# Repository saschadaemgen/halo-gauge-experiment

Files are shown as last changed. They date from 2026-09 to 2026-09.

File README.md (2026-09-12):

<p align="center">
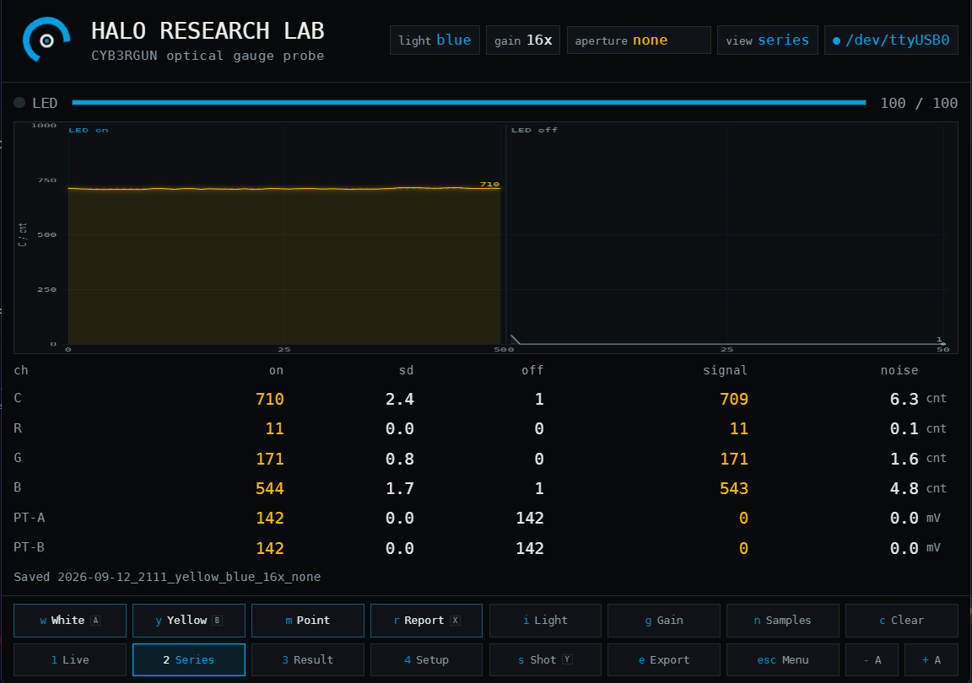
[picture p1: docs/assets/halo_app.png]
HALO LAB
  
</p>

<h1 align="center">halo-gauge-experiment</h1>

<p align="center">
  <strong>Reading an analog pressure gauge optically, from the outside, without touching it.</strong><br>
  A ring of cent-priced sensors, blue light, and the shadow of a needle.
  Open research, including the measurements that failed.
</p>

<p align="center">
  
  
  
  
  
  
</p>

---

The pressure gauge on a pre-charged pneumatic airgun sits inside a sealed,
type-approved system. Screwing in an electronic transducer means opening that
system, which for a gauge under German F-mark approval is not an option for the
owner and elsewhere is at best unwise.

So the needle is read from outside, through the glass, with the original gauge
left exactly as it is. Once the value is digital it can be displayed anywhere,
logged over time, compared against shot data, or fed into a head-up display.

This repository holds the whole thing: the printable test fixture, the probe
firmware, the measurement software, the raw data, and the five versions of the
fixture that were thrown away before the sixth worked.

---

## The Idea

Yellow absorbs blue. Under blue light a yellow needle is dark and a white dial
is bright, and the difference is large enough for a phototransistor that costs
thirty cents.

| | conventional approach | this approach |
|:--|:--|:--|
| **Sensor** | camera plus image processing | 16 to 37 phototransistors in an arc |
| **Contrast from** | ambient light and luck | illumination chosen against the needle pigment |
| **Power** | milliwatts, continuously | microwatts, emitter pulsed per reading |
| **Build height** | needs working distance for optics | under 10 mm over the glass |
| **Smallest dial** | 38 mm commercially | 20 mm |
| **Resolution** | pixels | ratio between two neighbouring sensors |

No image, no inference, no working distance. The pattern of light and dark
across the arc says where the needle is, and the ratio between two adjacent
sensors gives the position between them.

---

## Where This Stands

| Stage | Question | State |
|:--|:--|:--|
| **0** | Is the colour contrast large enough at all | **passed** |
| **0b** | Does the thirty-cent phototransistor see it too | **passed** |
| **0c** | Is blue the reason, or merely brightness | white emitter on order |
| **1** | How does one sensor see the needle sweep past | cards printed, fixture ready |
| **2** | Can two sensors interpolate the position between them | next |
| **3** | Does it survive the glass of a real gauge | after stage 2 |

### Stage 0 Result

Blue emitter, a white card against a card in the needle colour, ambient removed
by sampling with the emitter on and off. The threshold was fixed at an SNR of
10 **before** the first measurement.

| Sensor | White | Yellow | Ratio | Contrast | SNR |
|:--|--:|--:|--:|--:|--:|
| TCS34725, clear | 1068 cnt | 224 cnt | 4.8 | 79 % | 22 |
| TCS34725, blue | 828 cnt | 168 cnt | 4.9 | 80 % | 22 |
| ALS-PT19 | 2286 mV | 451 mV | 5.1 | 86 % | 160 |

Two independent sensors agree on a factor of five. With the emitter dark both
read exactly zero, which is also the proof that the chamber is light tight.

Raw output of every run, including the ones that went wrong, is in
[`docs/log/data/`](docs/log/data).

---

## Why It Matters Beyond One Gauge

Every PCP airgun has the same problem: a small dial, a coloured needle, a
housing nobody may open. What differs between a Huben, an Evanix, a Daystate or
an FX is dial diameter, sweep angle and needle colour.

All three are parameters, not redesigns, and the software treats them as
parameters from the first line. Enter a gauge, set a range and a step, and the
measurement plan, the file names and the printable test cards follow.

**The same method applies wherever a sealed instrument has to stay sealed.**
Diving cylinders, compressors, workshop manometers, breathing apparatus. The
one published patent closest to this project is for the pressure gauge of an
air respirator, for exactly that reason.

---

## The Fixture

A reflectance test bench in black PLA, for under 60 euro in parts.

| | |
|:--|:--|
| **Geometry** | 20/0. Emitter at twenty degrees, sensor looking straight down. Colour measurement normally uses 45/0, but under ten millimetres of build height there is no room for forty-five, and the ring will have the same constraint. |
| **Chamber** | closed box standing on the card. Emitter dark reads 0.00 counts. |
| **Field stop** | exchangeable card with a pierced hole. Printed holes below 1.5 mm do not exist after printing, which is why the aperture left the printer. |
| **Sensor pocket** | takes either sensor, so nothing but the sensor changes between two runs. |

This is **not** a spectrophotometer. Such an instrument measures absolutely and
calibrated, costs five figures, and measures under its own illumination. This
one measures relatively, white against yellow, under exactly the light source
and geometry the product will use. For this question that is the more relevant
number. For a colour standard it would be nonsense.

Parts, orientation and print settings: [`hardware/jig/README.md`](hardware/jig/README.md)
Method, wiring and evaluation: [`docs/method/measurement.md`](docs/method/measurement.md)
Six versions and why five were scrapped: [`docs/log/jig-versions.md`](docs/log/jig-versions.md)

---

## The Probe

A Heltec WiFi LoRa 32 V2 carrying a TCS34725 colour sensor and two ALS-PT19
phototransistors. It samples N times with the emitter on and N with it off,
returns mean and standard deviation per channel, and computes nothing else:
every number in this repository comes from the raw data, not from the firmware.

It speaks the same protocol over USB and over TCP, so the cable to the bench
computer can be pulled off, and it updates itself over WiFi, so the fixture can
be screwed shut for good.

```
w   white card        i   switch emitter, blue or white
y   yellow card       g   cycle colour sensor gain
m   one needle position, labelled by the software
n   samples per half series, 10 / 25 / 50 / 100
r   report contrast and SNR
```

---

## HALO LAB

<p align="center">
  HALO LAB measurement screen
</p>

The measurement front end. It reads the probe, shows the running series full
screen, and files every result three ways: a readable text record, the raw
JSON, and a row in an SQLite database. Gauges, campaigns and needle positions
are managed in the app, and the measurement plan is computed from the range and
the step size.

It runs as a self-contained instrument on a Clockwork uConsole, which boots
straight into it with no desktop in sight, and equally on any PC.

```bash
python3 software/labui/halo_lab.py --port /dev/ttyUSB0
# then open http://127.0.0.1:8760
```

Details: [`software/labui/README.md`](software/labui/README.md) and
[`software/launcher/README.md`](software/launcher/README.md)

---

## Getting Started

### 1. Print the fixture

Eleven parts, black PLA, 0.20 mm, no supports. See
[`hardware/jig/README.md`](hardware/jig/README.md) for orientation, which is
the part that is easy to get wrong.

### 2. Print the cards

```bash
python3 tools/make_cards.py --scale 3 --from 16 --to 24 --step 0.5 --show-radius
```

At 100 %, no scaling. Every sheet carries a ruler so a wrongly scaled print is
obvious before it is measured.

### 3. Wire and flash

Wiring table in [`docs/method/measurement.md`](docs/method/measurement.md).
Open [`firmware/halo_gauge_probe/`](firmware/halo_gauge_probe) in the Arduino
IDE, board **Heltec WiFi LoRa 32(V2)**, upload.

### 4. Measure

```bash
pip3 install pyserial
python3 software/labui/halo_lab.py --port COM6
```

White card, yellow card, report. Twenty seconds each.

---

## Contributing

**The most useful contribution is a measurement on a gauge this project has not
seen.** Another needle colour, another dial size, another manufacturer. If the
method holds across gauges, everything after it is calibration.

Negative results are wanted as much as positive ones. A gauge where this does
not work is worth more than a third one where it does.

Two house rules: measurements over opinions, and failures stay in the log.
[`CONTRIBUTING.md`](CONTRIBUTING.md)

---

## Prior Art

This is not the first optical gauge reader and does not pretend to be.

| | |
|:--|:--|
| **BAM, 2006** | reflective light barriers in a ring around a pointer axis, WO 2007/147609 |
| **Cypress Envirosystems, 2008** | clip-on camera reader, 38 to 114 mm dials, plus or minus 1.5 % of full scale |
| **Siemens, 2019** | patented sensor ring with triangular elements, active until 2040 |
| **AI-on-the-edge-device, 2020** | ESP32-CAM with TensorFlow Lite, the open source camera route |

What is new here: the wavelength chosen against the needle pigment, a 20 mm
dial, and published measurements. The delineation from the Siemens claim is
deliberate and documented, down to the design rule that follows from it.

Sources and the full review: [`docs/research/prior-art.md`](docs/research/prior-art.md)

---

## Repository

```
docs/research/      prior art: patents, commercial devices, open source
docs/method/        how the measurement is done and evaluated
docs/log/           build log, discarded versions, raw data
hardware/jig/       printable fixture, bill of materials, print settings
hardware/cards/     printable test cards
tools/              card generator for any dial, range, sweep and scale
firmware/           probe firmware for a Heltec WiFi LoRa 32 V2
software/labui/     HALO LAB, the measurement front end
software/launcher/  the terminal it runs on
```

---

## Licence

| What | Where | Licence |
|:--|:--|:--|
| Firmware, software, tools | `firmware/`, `software/`, `tools/` | **GPL-3.0-only** |
| Hardware, printable parts, card artwork | `hardware/` | **CERN-OHL-S-2.0** |
| Documentation and measurement data | `docs/`, `README.md` | **CC-BY-SA-4.0** |

Build it, change it, sell it. Keep the notice, say what you changed, pass the
same freedom on. Full text and the reasoning: [`LICENSE.md`](LICENSE.md)

---

## Origin and Trademarks

This project started inside the CYB3RGUN development and is published as a
standalone community project.

Huben, GK1 and any other manufacturer or product names are trademarks of their
respective owners. This project is not affiliated with or endorsed by any of
them. The test dials in this repository are original artwork and not copies of
any manufacturer's dial: only the geometry follows a real gauge, and geometry
is technical, not protectable.

<p align="center">
  <sub>Sascha Dämgen, 2026. Measured, not assumed.</sub>
</p>

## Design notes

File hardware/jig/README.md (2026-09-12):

# Test fixture V6

A light tight reflectance fixture with a 20/0 geometry, an exchangeable field
stop, and one pocket that takes either sensor. Printed in black PLA, all parts
flat, no supports, every bore vertical in print orientation.

See `docs/log/jig-versions.md` for how it got here and what not to repeat.

## Printed parts

| file | qty | size mm | print orientation |
|---|---|---|---|
| gauge_jig_base.stl | 1 | 120 x 120 x 4 | as exported, pocket up |
| jig_v6_rail.stl | 1 | 120 x 60 x 4 | flat |
| jig_v6_frame.stl | 1 | 46 x 46 x 14 | flipped: the face with the small 24 mm opening on the bed |
| jig_v6_slide.stl | 1 | 46 x 46 x 2 | flat, card recess up |
| jig_v6_carrier.stl | 1 | 46 x 46 x 26 | flat, board pocket up |
| jig_v6_lid_tcs.stl | 1 | 46 x 46 x 2 | flat |
| jig_v6_lid_pt19.stl | 1 | 46 x 46 x 2 | flat |
| jig_v6_led_holder.stl | 2 | 26 x 46 x 22 | as exported, standing on the slanted face |
| jig_v6_led_cap.stl | 2 | 11 x 28 x 3 | flat |
| jig_v6_pt19_insert.stl | 1 | 20.3 x 20.3 x 3.2 | flat, pocket up |
| jig_v5_pinhole_plates.stl | 1 print, four plates | 28 x 28 x 0.4 each | flat |

## Not printed

- M3 x 40, four off, through carrier and slide into the frame
- M3 x 10, four off, two per LED cap
- 2 LEDs, 5 mm, clear lens, one blue around 470 nm and one cold white
- 2 resistors to suit the supply, or an LED lead with one built in
- 2 logic level MOSFETs and 2 resistors of 47 k for the gate pull-down
- black photo card, matte, cut to 28 x 28 mm, hole pierced or drilled in the
  centre. This is the field stop. It does not come out of a printer.
- a TCS34725 breakout on the Adafruit 1334 layout, or an ALS-PT19 on the
  Adafruit 2748 layout. Headers soldered to the top, so the board lies
  component side down.

## Orientation, the part that is easy to get wrong

**Frame:** the open chamber with the two window cutouts goes face down onto the
card. The closed face with the small 24 mm opening and the print texture faces
up. Turn it the other way and the LEDs shine into a wall.

**LED holders:** flat face on the card, slanted face outwards. The LED goes in
from the slanted face, so its light leaves at the vertical inner face and
crosses the window of the frame on its way down to the spot.

**Slide:** recess up, the aperture card drops into it.

**Carrier:** pocket up, the sensor board lies in it component side down.

## Assembly

Card in the pocket, rail on the four pegs, frame in the middle of the rail
window, an LED holder either side of it. Slide on the frame, aperture card in
its recess, carrier on top, four long screws. Sensor board into the pocket, lid
on, done. LEDs in from outside, caps with two short screws each.

## Print settings, Bambu Lab P1S or P2S

Layer height 0.20 mm. The card recess in the slide is 0.4 mm deep, which is
exactly two layers. Another layer height rounds it to the wrong depth.

Black PLA. Lowest shrinkage of the common filaments, which matters for a stack
of parts that has to fit together, and black because white and clear filament
carry light through the walls.

Four perimeters, 30 % gyroid, seam aligned or rear. Check that the seam does
not fall inside the LED bore.

X-Y hole compensation stays at zero. It acts on every hole equally while small
holes shrink more than large ones, so no single value suits 2.5, 5.4 and 8 mm
at once. Ream the M3 tap holes with 2.5 mm and the LED bore with 5.5 mm only if
the LED will not slide in.

Print the slide first. It takes minutes, and if the aperture card sits in its
recess the rest is worth printing.

## Geometry

- card surface: 0
- frame chamber: 0 to 12, opening 24 x 24 from 12 to 14
- slide: 14 to 16, aperture card at about 15.75
- carrier: 16 to 42
- LED axis crosses the frame wall at 8.1 above the card, at 20 degrees

Spot diameter on the card is roughly 1.7 times the aperture plus 0.3 mm.

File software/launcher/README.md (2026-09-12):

# CYB3RGUN research terminal

Turns a Clockwork uConsole into an instrument: it boots into a menu of the
project's applications, no desktop, no Linux in sight.

## What it does

- `launcher.py` serves the start screen on port 8750 and knows which
  applications exist, whether they are running, and how to start them
- `apps.json` is that list. Adding a tool is an entry in a file, not code
- two systemd user services keep the launcher and HALO LAB alive across reboots
- the browser starts full screen on the launcher as soon as it answers
- `boot-splash.sh` replaces the Raspberry boot screens with the project's own

## Install

```
cd ~/halo-gauge-experiment
bash software/launcher/install.sh
bash software/launcher/boot-splash.sh
sudo reboot
```

Both scripts keep a backup of anything they change and can be run again
safely. `install.sh` appends to the labwc autostart rather than replacing it.

## The application list

```json
{
  "key": "1",
  "name": "HALO LAB",
  "line": "optical gauge probe",
  "detail": "contrast, needle sweep, campaigns",
  "url": "http://127.0.0.1:8760",
  "check": "127.0.0.1:8760",
  "service": "halo-lab"
}
```

`url` sends the browser somewhere, `run` starts a program, `check` is a
host:port that decides whether the tile shows as running, and `soon: true`
greys a tile out for something not built yet.

## Keys

Digits 1 to 9 start an application, `r` refreshes, `p` opens power, plus and
minus change the text size. The uConsole game buttons A, B, X and Y start the
first four tiles. The text size is remembered.

## Notes

Chromium is started with `--password-store=basic`, otherwise it asks for a
keyring password on every start, which on a kiosk is asking nobody.

If the power buttons do nothing, `systemctl poweroff` needs a polkit rule or a
sudoers line for this user.

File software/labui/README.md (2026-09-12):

# HALO LAB

Measurement front end for the halo-gauge-experiment probe. It reads the Heltec
board over USB, shows the running measurement full screen, and records every
finished series and report into `docs/log/data/`.

Built for the Clockwork uConsole at 1280 x 720, runs the same on any PC.

## Install

Only pyserial is needed. Everything else is the Python standard library.

    sudo apt install python3-serial          # Raspberry Pi OS
    pip3 install pyserial                    # anywhere else

For the screenshot button, `scrot` must be present. Without it the button
reports what is missing and nothing else breaks.

    sudo apt install scrot

## Run

    python3 software/labui/halo_lab.py --list          # which ports exist
    python3 software/labui/halo_lab.py                 # uses /dev/ttyUSB0 or COM6
    python3 software/labui/halo_lab.py --port COM6
    python3 software/labui/halo_lab.py --simulate      # no hardware, fake data

Then open http://127.0.0.1:8760

To reach it from another machine, for example the board on a PC and the screen
on the uConsole:

    python3 software/labui/halo_lab.py --host 0.0.0.0

Kiosk mode on the uConsole:

    chromium-browser --kiosk --app=http://127.0.0.1:8760

## Using it

The board is switched into JSON mode automatically on connect. Every button in
the footer is also a key on the keyboard, the letter is printed on the button.

| key | does |
|---|---|
| w | measure the white card |
| y | measure the yellow card |
| r | report contrast and SNR |
| i | switch light source, blue or white |
| g | cycle the colour sensor gain |
| c | clear stored results |
| s | screenshot into `docs/log/images/` |

Fill in the aperture field before measuring. It goes into the file names and
into the header of every record, which is the only way to tell two otherwise
identical series apart later.

## What gets written

Per finished series and per report, into `docs/log/data/`:

- `YYYY-MM-DD_HHMM_<target>_<light>_<gain>_<aperture>.txt`, the human readable
  record with a header naming firmware, light, gain, aperture and note
- the same stem with `.json`, holding the raw firmware object plus that metadata

Every serial line, parseable or not, is appended to
`docs/log/data/session_YYYY-MM-DD.log` with a timestamp. If anything else goes
wrong, that file still has the measurement in it.

## Colours

The palette is the experiment, not decoration. Blue is the light source and
anything the operator triggers, yellow is the needle and its measured values,
white is the dial. A go verdict is blue. A failed threshold is grey, because a
low reading is a result and not a fault. The only red is a lost serial link.

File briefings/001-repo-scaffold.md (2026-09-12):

# Briefing 001: Repository scaffold for halo-gauge-experiment

Author: Mausi (master chat)
Executor: Claude Code (CC)
Repository: https://github.com/saschadaemgen/halo-gauge-experiment (private)
Local root: C:\Projects\CYB3RGUN\HUBEN\halo-gauge-experiment

## Goal

Move the files that already sit in the local root into the repository layout, add the documentation files from the scaffold package, configure Git LFS for binary assets, and push four commits.

## Working rules

- Stop at the first failure and report the exact output. Do not improvise.
- Do not edit the content of any .md, .ino, .stl or .png file. This briefing is about placement and Git only.
- No em dashes anywhere in files you create. Use normal hyphens.
- Conventional Commits, one commit per concern, messages given below.

## Step 0: Verify state

```
git remote -v
git status
git lfs version
```

Remote must point to saschadaemgen/halo-gauge-experiment via SSH. Report the branch name. If Git LFS is missing, STOP and report.

List the current root. Expected: five `jig_v5_*.stl`, `jig_v5_sections.png`, `mhg01.png`, `mhgz01.png`, and the unpacked scaffold folder.

## Step 1: Target layout

```
halo-gauge-experiment/
  README.md
  .gitignore
  .gitattributes
  briefings/001-repo-scaffold.md
  docs/
    research/prior-art.md
    method/measurement.md
    log/jig-versions.md
    log/data/.gitkeep
  hardware/
    jig/README.md
    jig/gauge_jig_base.stl
    jig/jig_v5_frame.stl
    jig/jig_v5_slide.stl
    jig/jig_v5_carrier.stl
    jig/jig_v5_led_holder.stl
    jig/jig_v5_rail.stl
    jig/jig_v5_sections.png
    cards/mhg01.png
    cards/mhgz01.png
    cards/README.md
  firmware/probe/halo_gauge_probe.ino
```

Move the existing files with `git mv` where they are already tracked, plain move otherwise. `mhg01.png` is the dial artwork, `mhgz01.png` is the needle artwork.

Create `hardware/cards/README.md` with exactly this content:

```markdown
# Test cards

Source artwork exported from Illustrator, 1:1, dial diameter 20 mm.

- `mhg01.png` dial face without needle
- `mhgz01.png` needle, separate layer

Card format is 100 x 100 mm. The card set (full white, full yellow, nine dial cards with the needle at 0 to 40 MPa in 5 MPa steps) is generated from these two files. Print all cards on the same printer and paper.
```

## Step 2: .gitignore

```
# OS
Thumbs.db
.DS_Store

# Editors
.vscode/
.idea/

# Arduino build output
firmware/**/build/
*.bin
*.elf
```

## Step 3: .gitattributes and LFS

```
*.stl filter=lfs diff=lfs merge=lfs -text
*.png filter=lfs diff=lfs merge=lfs -text
*.jpg filter=lfs diff=lfs merge=lfs -text
*.pdf filter=lfs diff=lfs merge=lfs -text
*.3mf filter=lfs diff=lfs merge=lfs -text
```

Run `git lfs install` once. Because the STL and PNG files may already be committed as plain blobs, run `git lfs migrate import --include="*.stl,*.png" --everything` only if `git log --oneline | wc -l` is greater than 0 and the files appear in history. If the repository has no commits yet, skip the migration. Report which case applied.

## Step 4: Commits

```
chore(repo): add gitignore, gitattributes and LFS tracking
docs: add README, prior art, measurement method and jig version log
feat(hardware): add test jig v5 STL files, base plate and card artwork
feat(firmware): add halo gauge probe sketch for Heltec WiFi LoRa 32 V2
```

Then `git push -u origin <branch>`.

## Report back

1. Branch name and remote
2. Whether LFS migration was needed and its result
3. The four commit hashes and the push result
4. `git ls-files` output

No suggestions for next steps. Those come from the master chat.

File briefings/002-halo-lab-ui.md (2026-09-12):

# Briefing 002: HALO LAB, measurement software for the uConsole

Author: Mausi (master chat)
Executor: Claude Code (CC)
Repository: https://github.com/saschadaemgen/halo-gauge-experiment
Development machine: Windows PC, C:\Projects\CYB3RGUN\HUBEN\halo-gauge-experiment
Target machine: Clockwork uConsole, CM4, Clockwork Raspberry Pi OS image, 1280 x 720
Hardware under test: Heltec WiFi LoRa 32 V2 on USB, firmware probe-0.2

## Goal

A local measurement application that reads the probe firmware over USB, shows the running measurement on the uConsole screen, and writes every finished series to disk as a raw log and a JSON record. It replaces the serial monitor for all further experiments, and every screen of it will end up as a photograph in a public forum post.

## Working rules

- Stop at the first failure and report the exact output. Do not improvise around a missing dependency, report it.
- Ask before adding any dependency that is not in the list below.
- Code, comments, docstrings and UI text in English. No em dashes anywhere.
- Do not touch anything under `firmware/`, `hardware/`, `docs/research/` or `docs/method/`.
- Do not invent measurement logic. All numbers come from the firmware. The UI computes nothing except formatting.
- Conventional Commits, commit messages at the end.

## Protocol, firmware probe-0.2

Serial, 115200 baud, 8N1. The firmware starts in human readable mode. Sending `j` switches it to JSON mode and it answers with a `hello` object. In JSON mode every line is exactly one JSON object with a `type` field. Single character commands, no line ending required:

| key | effect |
|---|---|
| `j` | toggle JSON mode, emits `hello` when switching on |
| `p` | emit `hello` again (status poll) |
| `w` | run a series on the white card |
| `y` | run a series on the yellow card |
| `r` | emit the report for every light source that has both targets |
| `i` | switch light source, blue or white, emits `ack` |
| `g` | cycle TCS34725 gain 1x / 4x / 16x / 60x, emits `ack` |
| `l` | toggle live stream, emits `ack` |
| `c` | clear stored results, emits `ack` |

Object types:

```
{"type":"hello","fw":"probe-0.2","tcs":0,"oled":1,"light":"blue","gain":"16x","samples":50}
{"type":"ack","cmd":"g","light":"blue","gain":"60x","live":1}
{"type":"live","t":123456,"c":0,"r":0,"g":0,"b":0,"pta":2286.3,"ptb":142.0,"sat":0,"light":"blue","gain":"60x"}
{"type":"run","target":"white","light":"blue","gain":"60x","samples":50}
{"type":"sample","target":"white","led":1,"n":0,"c":0,"r":0,"g":0,"b":0,"pta":2286.0,"ptb":142.0}
{"type":"series","target":"white","light":"blue","gain":"60x","samples":50,"saturated":0,
 "on":{"C":[1067.70,38.53],"R":[...],"G":[...],"B":[...],"PT-A":[...],"PT-B":[...]},
 "off":{...},"signal":{"C":1067.70,...},"noise":{"C":38.53,...}}
{"type":"report","light":"blue","saturated":0,
 "channels":[{"ch":"C","unit":"cnt","white":1067.70,"yellow":224.10,"contrast":0.7901,"noise":38.76,"snr":21.80,"go":1}, ...],
 "best":"B","best_snr":22.00,"go":1}
{"type":"error","msg":"unknown command x"}
```

In `on`/`off` each channel is `[mean, sd]`. Channel order is always C, R, G, B, PT-A, PT-B. `contrast` is a fraction, display it as a percentage. A run emits one `run`, then 100 `sample` objects (50 with `led:1`, 50 with `led:0`), then one `series`. A run takes about 20 seconds.

Unparseable lines are not an error: the firmware may print a boot banner or a stray human line. Ignore any line that is not valid JSON, but keep it in the raw log.

## Architecture

Python 3 on the uConsole. A local HTTP server on 127.0.0.1:8760 serves one page and a websocket. The browser runs in kiosk mode and shows it full screen. Reason for this split: the same code runs on a normal PC, and the screen is easy to make look good.

Dependencies, all from apt or pip on the Pi: `pyserial`, `websockets`, `aiohttp`. Nothing else. No build step, no npm, no bundler. The page is one HTML file with inline CSS and JavaScript plus the logo SVG, served from `software/labui/static/`.

```
software/labui/
  README.md            how to install and run, on the Pi and on a PC
  halo_lab.py          server: serial reader, JSON parser, websocket, file writer
  static/index.html    the whole UI
  static/cyb3rgun_logo.svg
```

Serial port: default `/dev/ttyUSB0`, override with `--port`. On Windows `COM6`. Add `--list` to print available ports and exit. If the port is missing or busy, the UI must still load and show a clear disconnected state with the port name and a retry button. Reconnect automatically every 2 seconds while disconnected.

## Files written per series

Directory `docs/log/data/`, created if missing. Two files per finished series, same stem:

`YYYY-MM-DD_HHMM_<target>_<light>_<gain>_<aperture>.txt` and `.json`

`<aperture>` comes from an input field in the UI, free text, default `none`, sanitised to lowercase with non alphanumerics replaced by `-`. The `.txt` is a human readable record in the same layout the firmware prints in text mode, with a header block naming date, firmware version, sensor, light, gain, aperture, sample count and the operator note. The `.json` holds the raw `series` object plus that same metadata under a `meta` key.

A report is written as `YYYY-MM-DD_HHMM_report_<light>_<aperture>.txt` and `.json` when it arrives.

Every raw serial line, JSON or not, is appended to `docs/log/data/session_YYYY-MM-DD.log` with a millisecond timestamp. That file is the fallback if anything else goes wrong.

## Screen

Fixed 1280 x 720, no page scrolling, nothing may be cut off. Design it once for that size, do not build a responsive grid.

Layout, left to right:

```
+--------------------------------------------------------------+
| [logo]  HALO LAB          blue - 60x - 1.0 mm     probe-0.2   |  56 px header
+---------------------+----------------------+-----------------+
|  LIVE               |  SERIES              |  RESULT         |
|  six channel bars,  |  the running series   |  report table,  |
|  value in mV / cnt  |  as a strip chart,    |  one row per    |
|  saturation flag    |  LED on and off runs  |  channel, GO or |
|                     |  drawn apart          |  no per row     |
|                     |                      |  verdict block  |
+---------------------+----------------------+-----------------+
|  w white   y yellow   r report   i light   g gain   c clear   |  72 px footer
+--------------------------------------------------------------+
```

Behaviour:

- The header always shows the current light source, gain and aperture, because every photograph of this screen has to be self explanatory.
- During a run the whole screen shows it: a progress bar with the sample count, the LED state as a labelled indicator, and the strip chart filling left to right. The other panels stay visible but dim.
- When a `series` arrives, its numbers replace the series panel: mean and sd for LED on and off, signal and noise per channel, saturation warning if the firmware sets it.
- When a `report` arrives, the result panel fills. The verdict block states the best channel, its SNR and whether the threshold of 10 is met, in words, not just a colour.
- The footer buttons send the keys. They are also bound to the keyboard, because the uConsole has one. Show the key letter on each button.
- An aperture field and a one line operator note field sit in the footer. Both go into the file metadata. Changing them does not send anything to the firmware.
- A camera button saves a PNG screenshot of the page into `docs/log/images/` with the same name stem as the last series. Use `html2canvas` only if it can be vendored as a single local file, otherwise leave the button out and say so in the report.

## Visual direction

The palette is not decoration, it is the experiment: the light source is blue, the needle is yellow, the dial is white. Use exactly those three as the meaningful colours and let the rest be dark and quiet.

```
--bg      #0A0C0E   near black, the inside of the light chamber
--panel   #12161A   panel fill
--line    #1E252B   hairlines and panel borders
--ink     #C9D3DA   body text
--dim     #6B7A85   labels and secondary text
--beam    #009FE3   CYB3RGUN blue, the light source, primary accent
--needle  #FCB803   needle yellow, measured from the gauge artwork
--dial    #F1EFE8   dial white
```

Rules for using them: the blue belongs to the light and to anything the operator triggers. The yellow belongs to the yellow card and its measured values. The white belongs to the white card. A GO verdict is blue, not green. A failed threshold is dim grey, not red, because a low contrast reading is a result and not a fault. The only red in the application is a lost serial connection.

Type: one monospace family for everything, because this is an instrument and the numbers must align. Use the stack `"DejaVu Sans Mono", "Liberation Mono", monospace`, which is present on the Clockwork image. No web fonts, the machine may be offline. Measured values are the largest type on the screen. Labels are small and quiet, in sentence case, not all caps.

The logo sits top left at 28 px, unmodified, in its own blue. Do not tint it, do not put it behind anything, do not repeat it.

Motion: exactly two moving things, the live bars and the strip chart, both driven by data. No transitions on buttons, no fades, no glow. The instrument look comes from precision and alignment, not from effects. Do not add scan lines, grid overlays, flicker, glitch text or terminal typing effects.

Numbers: fixed decimal places per channel, right aligned, with the unit in a separate dim column so the digits line up. Never let a value change its width while updating.

## Acceptance

1. `python3 halo_lab.py --list` prints the available serial ports.
2. With the Heltec connected, `python3 halo_lab.py` starts, the page loads at http://127.0.0.1:8760, the header shows firmware version and light source within two seconds.
3. Unplugging the Heltec shows the disconnected state, plugging it back in recovers without restarting the program.
4. Pressing `w` runs a series, the progress and the strip chart follow it live, and afterwards the numbers match what the firmware printed.
5. After `w`, `y` and `r`, four data files and one session log exist under `docs/log/data/` and the values in them match the screen.
6. The page fits 1280 x 720 with no scrollbar and no clipped text.

## Commits

```
feat(labui): add serial reader and websocket server for probe-0.2
feat(labui): add HALO LAB measurement screen
docs(labui): add install and run instructions
```

## Build hint

No firmware change in this briefing, so no flashing. On the uConsole: `git pull`, then `python3 software/labui/halo_lab.py`. If dependencies are missing, report the exact `pip install` line rather than running it blind.

## Report back

1. Python version on the PC and, if you touched it, on the uConsole
2. The dependency list actually installed
3. Whether the screenshot button was implemented, and if not, why
4. A description of what the screen shows in the disconnected state
5. The three commit hashes and the push result

No suggestions for next steps.

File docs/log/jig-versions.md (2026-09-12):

# Test fixture, version history

How the fixture got to V6, and why each version was thrown away. The reasons
are the design rules for the sensor ring, which is why they are written down.

## V1, 2026-09-08

Base plate with a card pocket, a bridge over it carrying the sensor board, and
five printed aperture discs of 5 mm diameter with holes from 0.6 to 3.0 mm.
LED channels bored at 28 degrees through the solid bridge.

Discarded:

- The 0.6 mm printed hole did not exist after printing, even at 0.08 mm layer
  height. FDM does not make clean holes below about 1.5 mm.
- 5 mm discs are too small to handle and cannot be seated repeatably.
- Angled bores through a solid body print badly. The roof of the bore sags and
  the LED sits crooked.
- The tunnel under the bridge was open along both long sides, so ambient light
  reached the card from the side.

## V2 and V3, 2026-09-09

The same bridge with light skirts along both edges, first with a 0.3 mm gap
above the card, then touching it. Fixed the side leak and none of the rest.

## V4, 2026-09-09

First modular stack: frame, aperture slide, sensor carrier, clamshell plugs for
3 mm LEDs, rail. Every part flat, every bore vertical in print orientation, the
aperture moved out of the printer and into a pierced black card.

Discarded before printing: the LEDs on hand are 5 mm, and the clamshell plug
does not scale to a 5 mm body inside the frame.

Lesson: confirm the dimensions of a component before drawing its holder.

## V5, 2026-09-09

The 5 mm LEDs moved out of the frame into their own blocks standing beside it,
each with a straight bore aimed at the measurement spot and an outer face cut
perpendicular to that bore, so the part prints standing with the bore vertical.
Pins of 1.75 mm filament aligned the stack.

Discarded: the pins align but hold nothing. The stack rattled, and a rattling
stack changes the geometry between two series, which is the one thing a
reference fixture must not do.

## V6, 2026-09-10, current

```
base plate   120 x 120 x 4    card pocket, four pegs
rail         120 x 60 x 4     locates frame and LED holders on the card
frame        46 x 46 x 14     light chamber, windows in two walls
slide        46 x 46 x 2      holds the aperture card
carrier      46 x 46 x 26     sensor pocket, 8 mm shaft
lid          46 x 46 x 2      closes the sensor pocket, slot for the header
LED holder   26 x 46 x 22     two off, 5 mm LED at 20 degrees
LED cap      11 x 28 x 3      two off, presses the LED flange flat
insert       20.3 x 20.3 x 3.2  carries an ALS-PT19 in the sensor pocket
```

Everything is screwed with M3 straight into the printed plastic. The stack no
longer moves between series.

### Rules that came out of V1 to V5

1. Every printed bore is vertical in its print orientation.
2. No printed hole below 1.5 mm. Small apertures go into black card.
3. Anything that has to be handled is at least 20 mm across.
4. Light tightness is a closed box standing on the target, not a roof over it.
5. Alignment is not fixation. If it can rattle, it will, and it will do it
   between two series.
6. Component dimensions are confirmed before the holder is drawn.

### Things that cost an evening and are worth writing down

**The breadboard rail is split in the middle.** The MOSFET had no ground at
all, and every measurement that followed was wrong until a multimeter found it.

**A logic level MOSFET from an unknown batch may not be one.** With 3.3 V on
the gate it held 2.1 V across drain and source instead of under 0.1. The LED
lit, dimly, and the contrast measurement still worked because contrast is a
ratio. The absolute numbers from that session are not comparable with later
ones and are labelled accordingly.

**The tower was a mistake.** A carrier that hangs the sensor deeper into the
chamber sounds like it gets closer to the card. It got further away, and the
phototransistor sat on the converter floor until the short carrier went back in.

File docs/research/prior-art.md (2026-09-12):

# Prior art

Last reviewed: 2026-09-09. This page is a technical review, not legal advice.

## Summary

Reading a pointer instrument optically from the outside is an old idea. Three families exist:

1. Reflective sensor rings: several light sensors on an arc above the dial, the pointer shades some of them. Documented since 2006, refined and patented by Siemens in 2019.
2. Camera based readers: image the dial, find the needle by image processing. Commercial since 2008, open source since 2020.
3. Mechanical or magnetic retrofits: magnet on the Bourdon tube with a Hall sensor, or replacing the gauge with a transducer. Invasive, not applicable to a sealed, type-approved pressure system.

This project belongs to family 1. It does not claim to have invented the sensor ring. What it adds is listed at the end.

## Patents

### Siemens AG, US 12,044,549 B2 and DE 10 2019 207 322 B4

Title: Optical reading device for a pointer instrument. Inventors: Ralf Huck, Stefan Klehr. Priority 2019-05-20 (DE 10 2019 207 322.0). US grant 2024-07-23, active until 2040-10-31. German family member granted 2021-07-29, active.

https://patents.google.com/patent/US12044549B2/en
https://patents.google.com/patent/DE102019207322B4/en

Claim 1 (US):

> An optical reading device of a pointer instrument having a pointer and a scale face or dial with different reflection properties, comprising: an illumination apparatus for illuminating the scale face or dial of the pointer instrument; and a plurality of triangular light sensor elements which are arranged in a circle about a rotation axis of the pointer for capturing light of the illumination apparatus reflected back by the scale face or dial of the pointer instrument; wherein the illumination apparatus is configured to evenly illuminate the scale face or dial at least in a region opposite the circle; and wherein the plurality of triangular light sensor elements each substantially formed as isosceles triangles and are each arranged adjacent to one another along a circumferential direction of the circle.

The inventive core is the triangular element shape. Because adjacent isosceles triangles are offset by half their base width, the pointer always shades two neighbours at once and the ratio of the two shadings gives a continuous position. Dependent claims cover 180 degree alternation, abutting limbs, triangular light guides made of transparent plastic, and ambient light collection.

Relevance to this project: the sensor elements here are rectangular SMD phototransistors (0603) behind printed baffles. They are not triangular and not arranged as abutting isosceles triangles. As read by the authors, claim 1 is therefore not met. Design rule derived from this: no triangular sensor elements, no triangular light guides. A freedom-to-operate opinion by a patent attorney is planned before any commercial sale, with DE 10 2019 207 322 B4 as the primary reference.

Technical lessons taken from the description: switch the LED on only for the duration of a reading; use an ambient light sensor to skip the LED when daylight suffices; uniform illumination of the sensed arc is essential and Siemens uses an annular light guide for it.

### BAM, WO 2007/147609 A2

Bundesanstalt fuer Materialforschung und -pruefung. Monitoring device for a measuring device. Priority June 2006.

https://patents.google.com/patent/WO2007147609A2/en

Describes a light source and a sensor fastened on the glass of a pointer instrument, working as a reflective light barrier that detects when the pointer reaches a predetermined position, and several such units arranged in a ring around the pointer axis to capture the position in segments. Mounting on an acrylic carrier by screws, snap fit or adhesive.

This is the sensor ring in its coarse, segment-wise form and is the closest published ancestor of this project. Any national patents from this application expire in 2027 at the latest. Status to be checked in DEPATISnet before commercial sale.

### Further patents cited by the Siemens examiner

- Rosemount Inc., US 2014/0239151 A1, self-powered optical detector for mechanical gauge instruments (2013).
- Shanghai Fire Research Institute, CN 103234593 A, digitizer for the pointer pressure gauge of an air respirator (2013). Closest application: small gauge on a sealed breathing air system.
- Lipman Science and Technology, US 2008/0048879 A1, automatic monitoring of analog gauges (2004).
- Baumer Bourdon-Haenni, EP 2905595 A1, gauge testing device, camera based (2014).

## Commercial products

### Cypress Envirosystems Wireless Gauge Reader (WGR)

https://cypressenvirosystems.com/products/wireless-gauge-reader-2/

Clip-on reader for existing gauges, on the market since 2008, patented. Reads the needle optically, transmits wirelessly. Gauge diameters 38 to 114 mm, accuracy stated as +/- 1.5 % of full scale. The user manual lists an image capture mode, so the device is camera based.

Lessons: "non-invasive, the pressure system stays sealed" has been the central selling argument of this device class for 17 years. +/- 1.5 % of full scale is the benchmark to beat or match. Dials below 38 mm are not served.

## Open source

### AI-on-the-edge-device

https://github.com/jomjol/AI-on-the-edge-device

ESP32-CAM with TensorFlow Lite, reads water, gas and electricity meters including the small analog pointer dials, everything on the device. Large community, maintained since 2020, commercial boards available.

Why this project does not use a camera: power. The sensor ring needs a few photodiodes and a briefly pulsed LED, which allows battery or energy harvesting operation. A camera plus inference costs orders of magnitude more energy and does not fit a device that lives in a pistol grip.

## What this project adds

1. Spectral contrast optimisation. None of the sources above selects the illumination wavelength for the needle pigment. The Huben GK1 needle is yellow on a white dial. Yellow pigment absorbs blue, so blue illumination (around 470 nm) with a broadband detector maximises the needle to dial contrast. This is the hypothesis the first experiment tests.
2. Dial size. Commercial readers start at 38 mm. This project targets a 20 mm dial with 0603 phototransistors at about 1.3 mm pitch on a 7 mm radius.
3. Application. A type-approved airgun pressure system that must not be modified, read from a battery powered grip.
4. Published method. Test jig, test cards, SNR threshold and raw data are public, including negative results.

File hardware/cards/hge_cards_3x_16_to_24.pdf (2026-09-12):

## HGE-D01 16.0 MPa

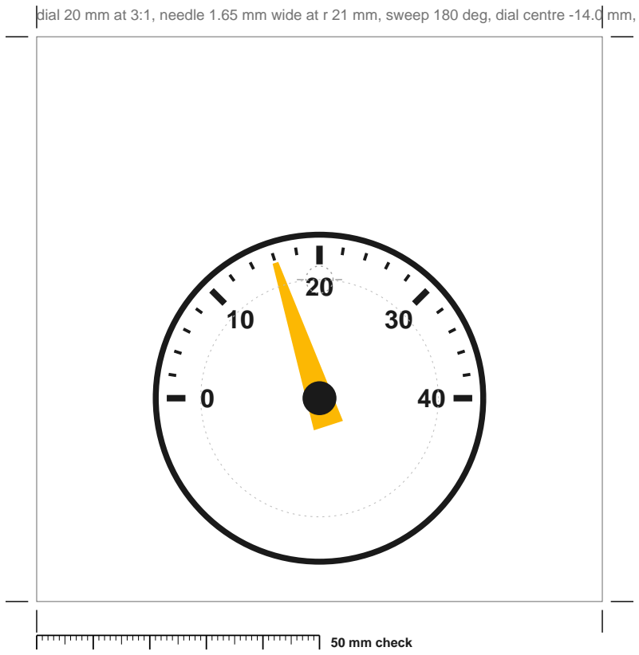
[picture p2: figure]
50 mm check

dial 20 mm at 3:1, needle 1.65 mm wide at r 21 mm, sweep 180 deg, dial centre -14.0 mm, 1 of 17

PRINT AT 100 %, NO SCALING. halo-gauge-experiment, Sascha Daemgen. Original artwork, not a copy of any manufacturer's dial.

## HGE-D02 16.5 MPa

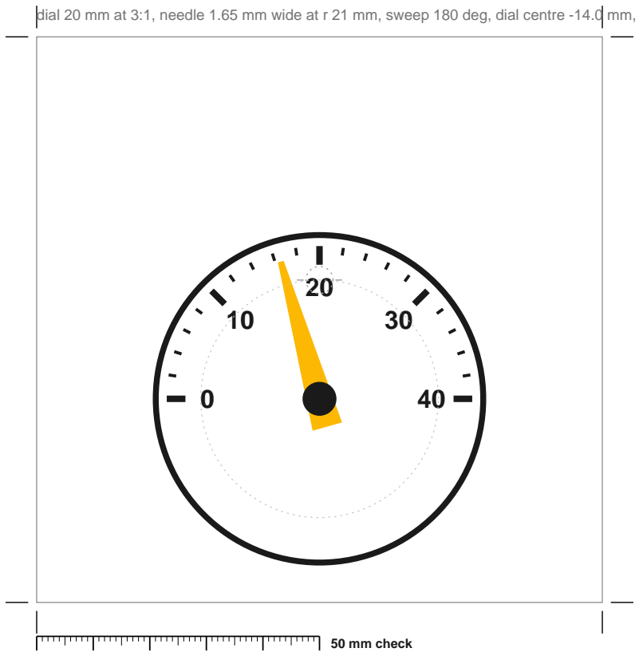
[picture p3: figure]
50 mm check

dial 20 mm at 3:1, needle 1.65 mm wide at r 21 mm, sweep 180 deg, dial centre -14.0 mm, 2 of 17

PRINT AT 100 %, NO SCALING. halo-gauge-experiment, Sascha Daemgen. Original artwork, not a copy of any manufacturer's dial.

## HGE-D03 17.0 MPa

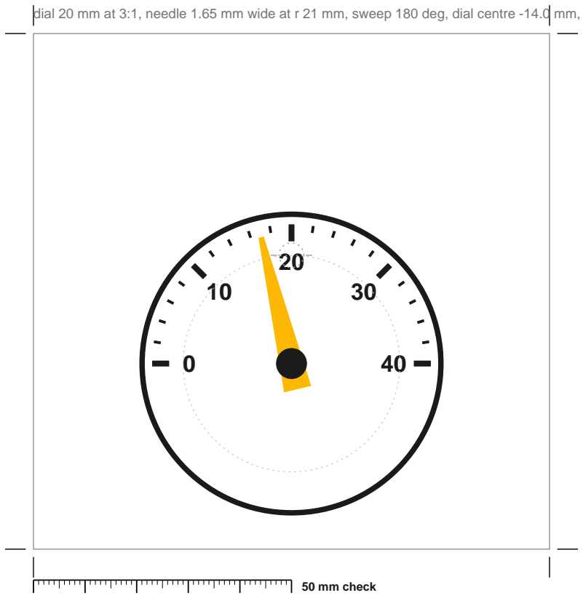
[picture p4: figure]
50 mm check

dial 20 mm at 3:1, needle 1.65 mm wide at r 21 mm, sweep 180 deg, dial centre -14.0 mm, 3 of 17

PRINT AT 100 %, NO SCALING. halo-gauge-experiment, Sascha Daemgen. Original artwork, not a copy of any manufacturer's dial.

## HGE-D04 17.5 MPa

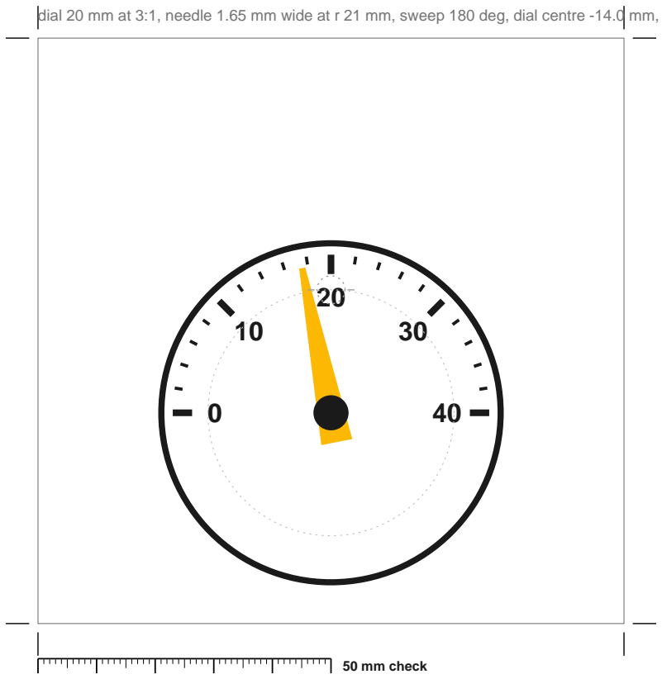
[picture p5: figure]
50 mm check

dial 20 mm at 3:1, needle 1.65 mm wide at r 21 mm, sweep 180 deg, dial centre -14.0 mm, 4 of 17

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

## HGE-D05 18.0 MPa

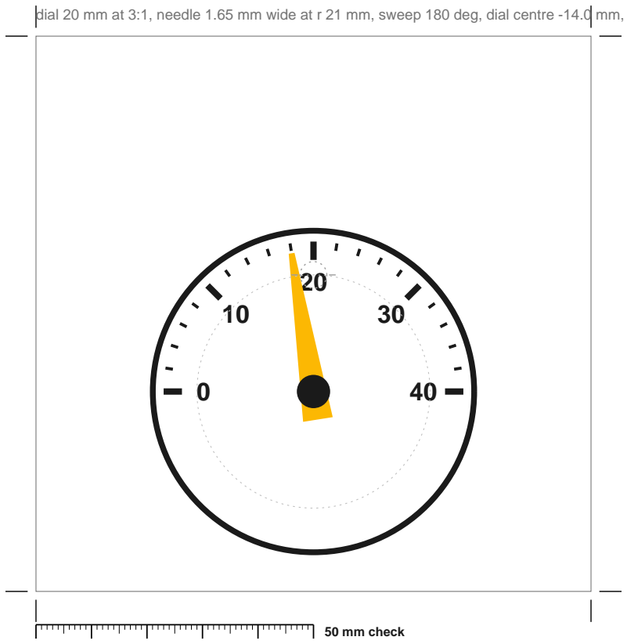
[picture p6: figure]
50 mm check

dial 20 mm at 3:1, needle 1.65 mm wide at r 21 mm, sweep 180 deg, dial centre -14.0 mm, 5 of 17

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

## HGE-D06 18.5 MPa

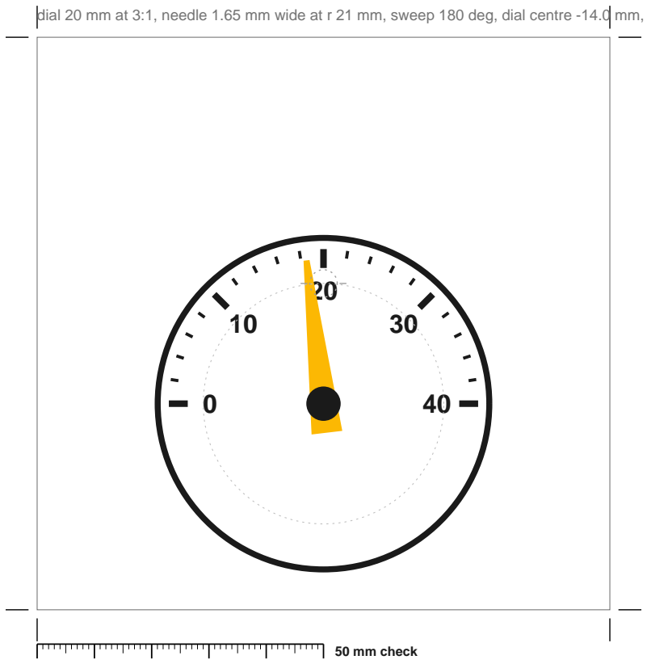
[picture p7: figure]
50 mm check

dial 20 mm at 3:1, needle 1.65 mm wide at r 21 mm, sweep 180 deg, dial centre -14.0 mm, 6 of 17

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

## HGE-D07 19.0 MPa

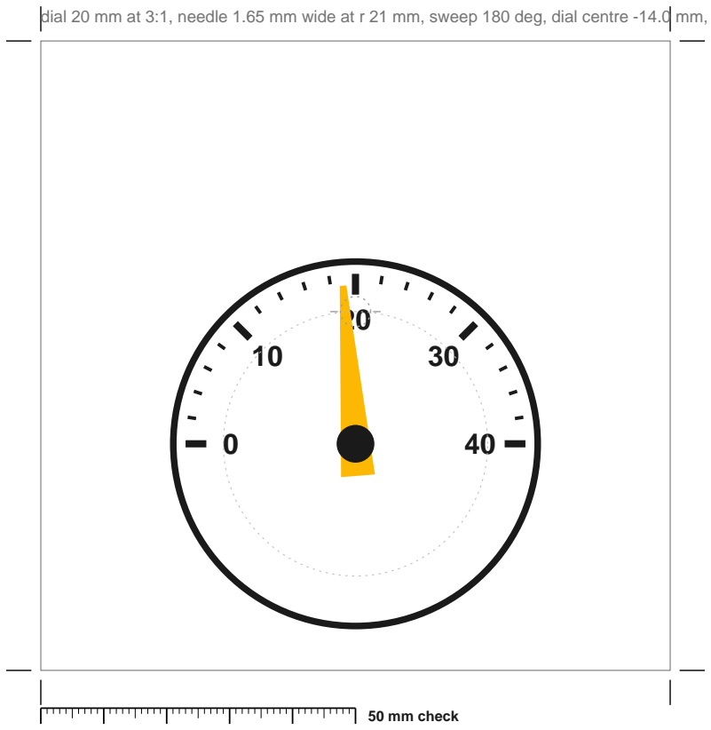
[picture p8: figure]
50 mm check

dial 20 mm at 3:1, needle 1.65 mm wide at r 21 mm, sweep 180 deg, dial centre -14.0 mm, 7 of 17

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

## HGE-D08 19.5 MPa

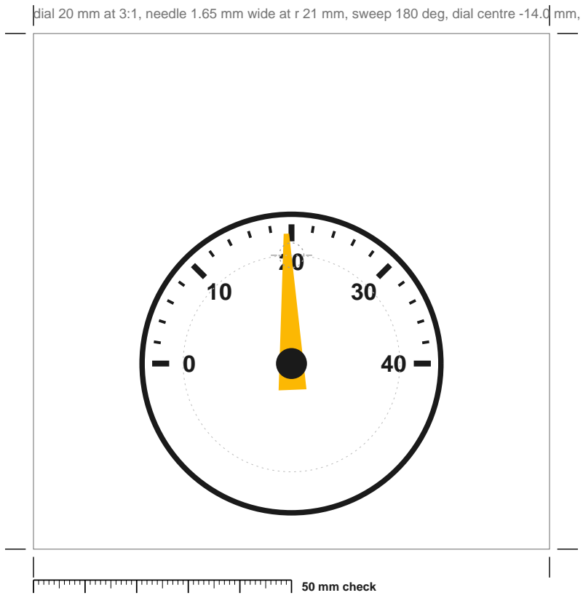
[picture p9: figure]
50 mm check

dial 20 mm at 3:1, needle 1.65 mm wide at r 21 mm, sweep 180 deg, dial centre -14.0 mm, 8 of 17

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

## HGE-D09 20.0 MPa

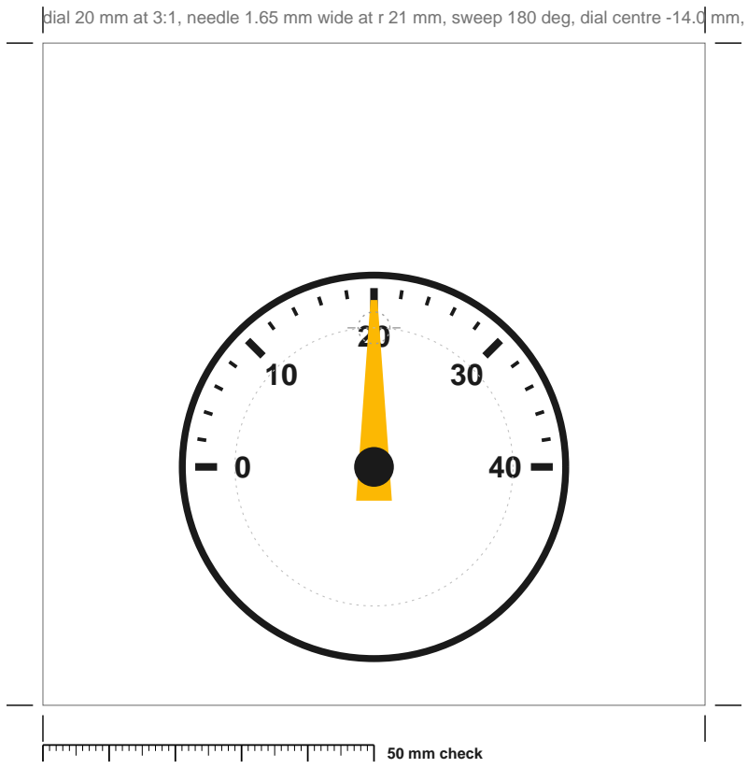
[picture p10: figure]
50 mm check

dial 20 mm at 3:1, needle 1.65 mm wide at r 21 mm, sweep 180 deg, dial centre -14.0 mm, 9 of 17

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

## HGE-D10 20.5 MPa

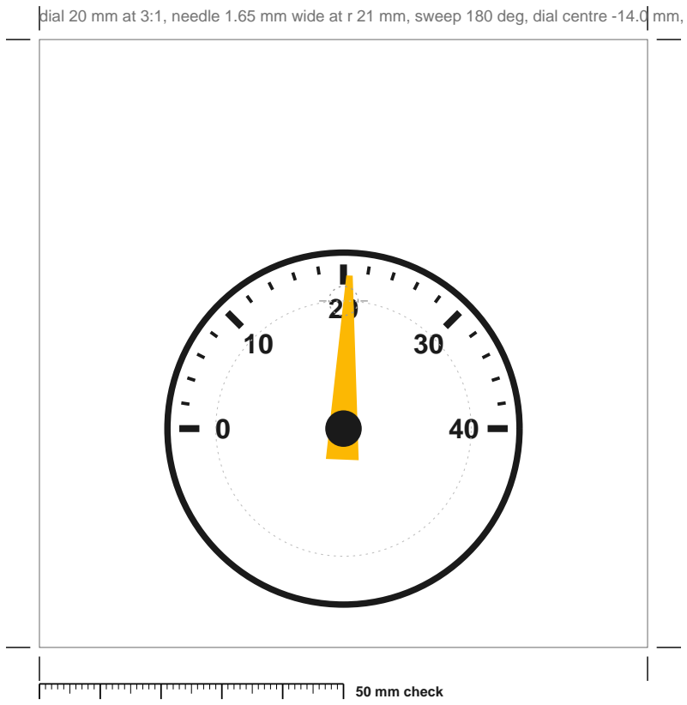
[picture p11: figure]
50 mm check

dial 20 mm at 3:1, needle 1.65 mm wide at r 21 mm, sweep 180 deg, dial centre -14.0 mm, 10 of 17

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

## HGE-D11 21.0 MPa

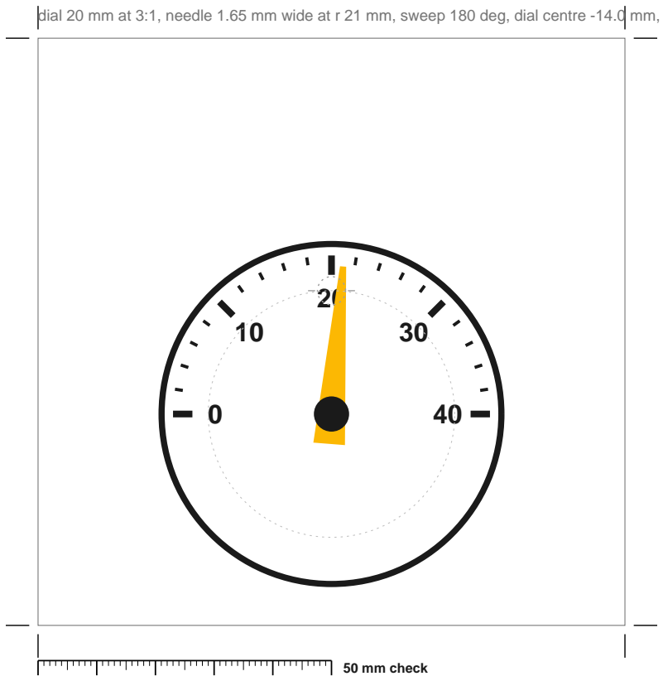
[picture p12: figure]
50 mm check

dial 20 mm at 3:1, needle 1.65 mm wide at r 21 mm, sweep 180 deg, dial centre -14.0 mm, 11 of 17

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

## HGE-D12 21.5 MPa

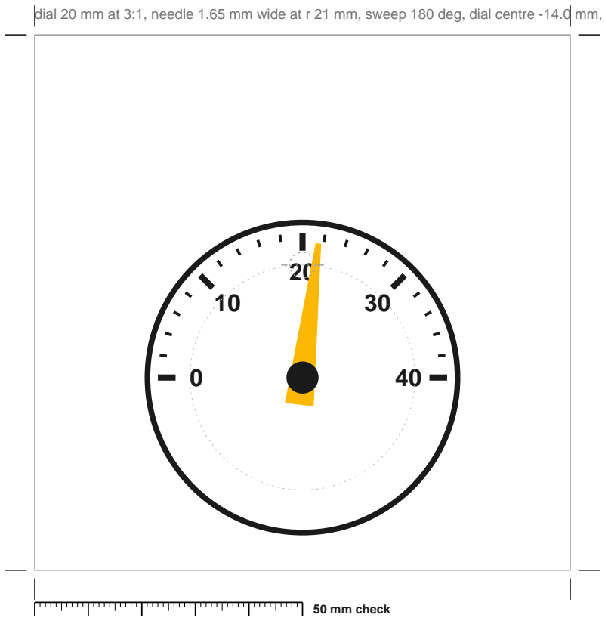
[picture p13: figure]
50 mm check

dial 20 mm at 3:1, needle 1.65 mm wide at r 21 mm, sweep 180 deg, dial centre -14.0 mm, 12 of 17

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

## HGE-D13 22.0 MPa

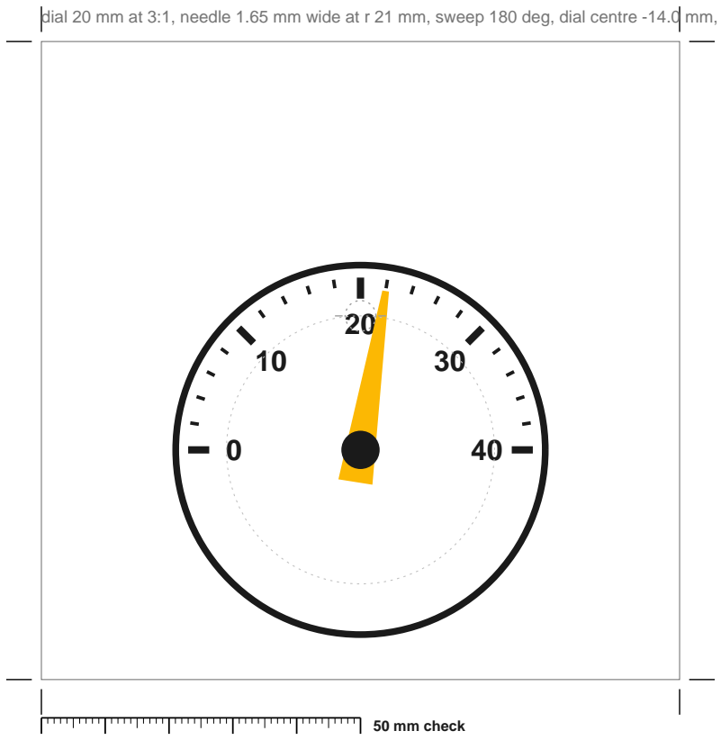
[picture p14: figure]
50 mm check

dial 20 mm at 3:1, needle 1.65 mm wide at r 21 mm, sweep 180 deg, dial centre -14.0 mm, 13 of 17

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

## HGE-D14 22.5 MPa

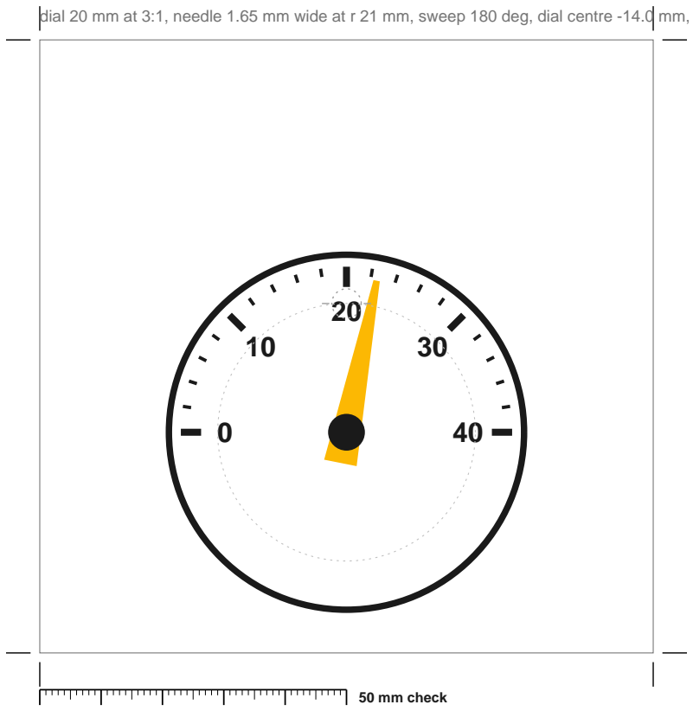
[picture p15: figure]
50 mm check

dial 20 mm at 3:1, needle 1.65 mm wide at r 21 mm, sweep 180 deg, dial centre -14.0 mm, 14 of 17

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

## HGE-D15 23.0 MPa

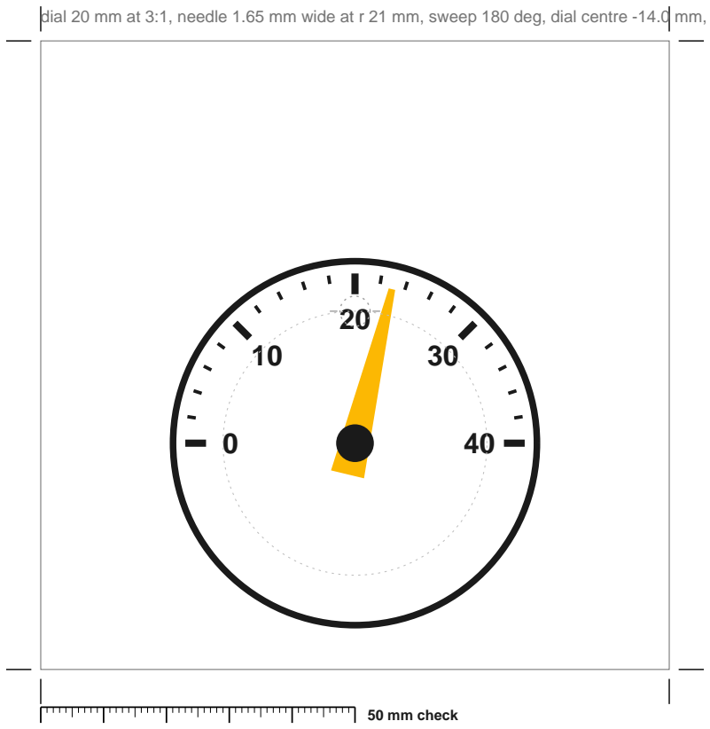
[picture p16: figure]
50 mm check

dial 20 mm at 3:1, needle 1.65 mm wide at r 21 mm, sweep 180 deg, dial centre -14.0 mm, 15 of 17

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

## HGE-D16 23.5 MPa

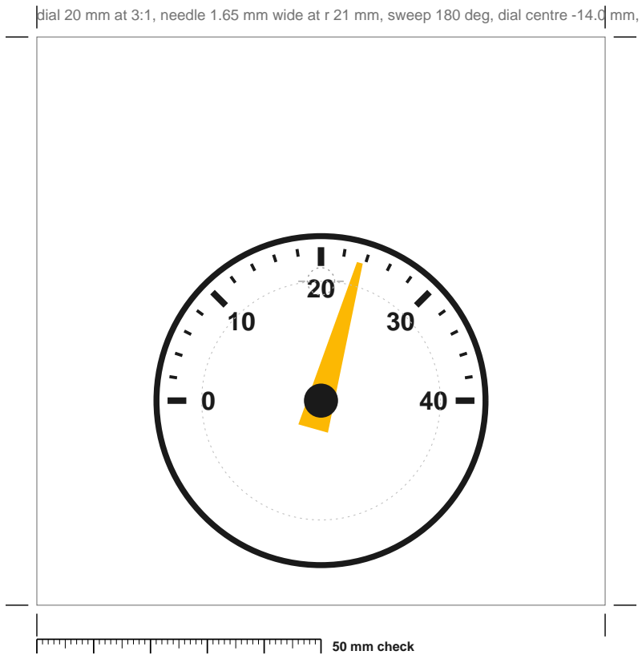
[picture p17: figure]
50 mm check

dial 20 mm at 3:1, needle 1.65 mm wide at r 21 mm, sweep 180 deg, dial centre -14.0 mm, 16 of 17

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

## HGE-D17 24.0 MPa

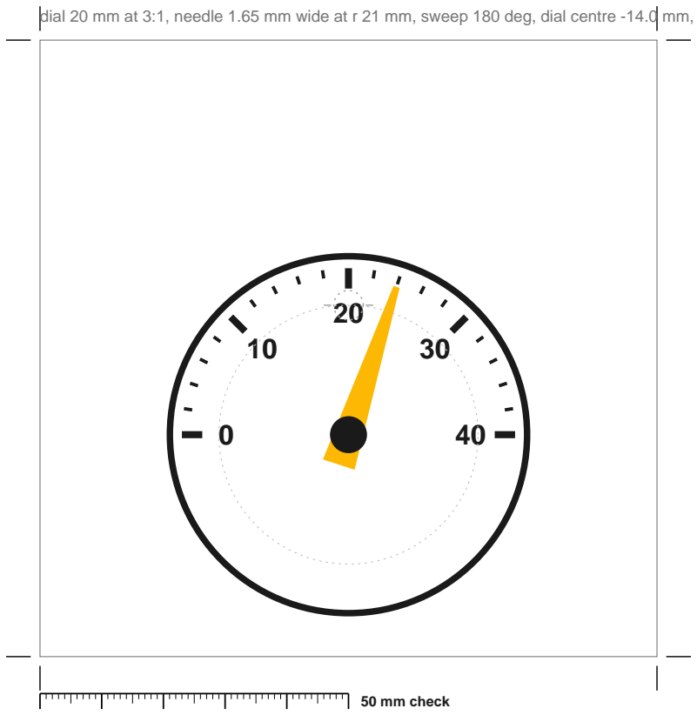
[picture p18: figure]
50 mm check

dial 20 mm at 3:1, needle 1.65 mm wide at r 21 mm, sweep 180 deg, dial centre -14.0 mm, 17 of 17

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

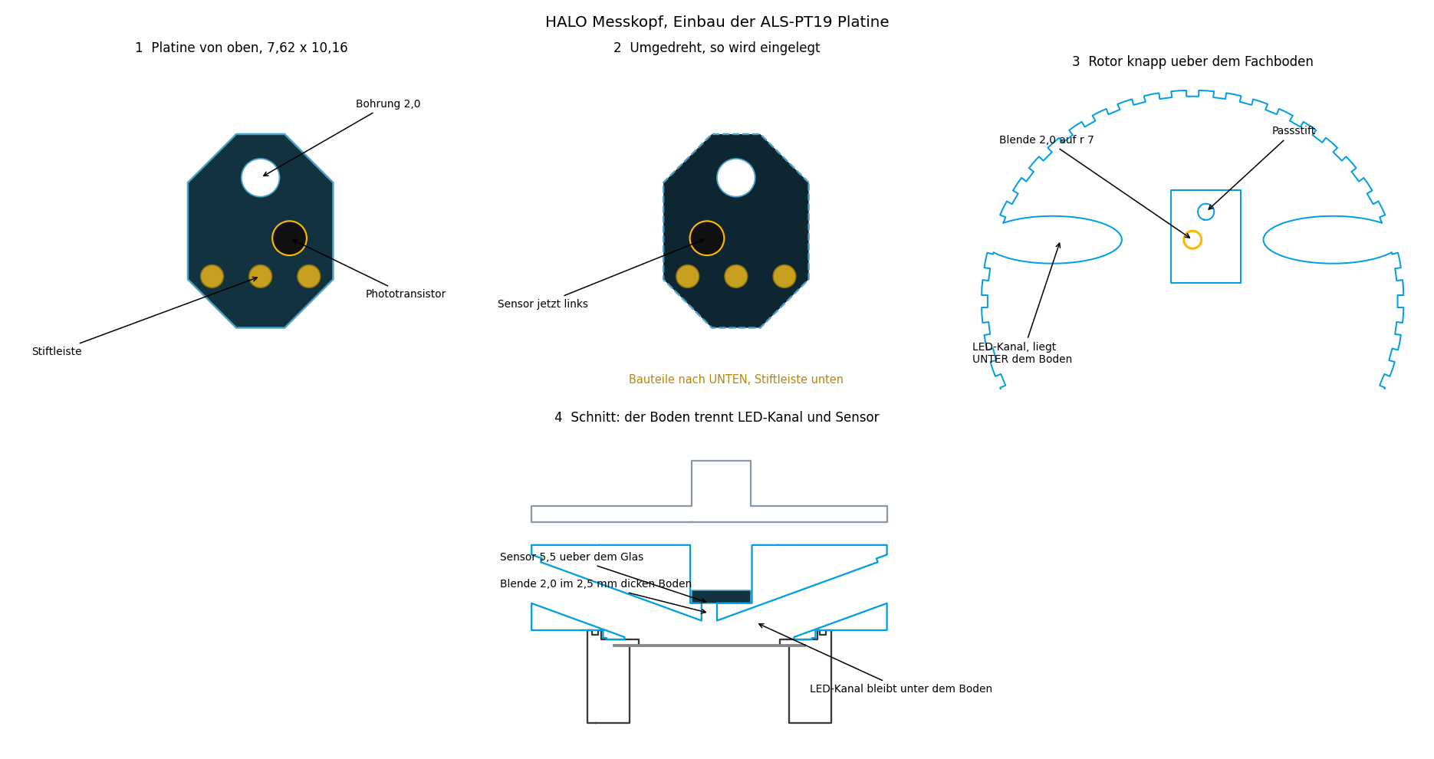
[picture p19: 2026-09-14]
hardware/jig/halo_head_einbau (1).png

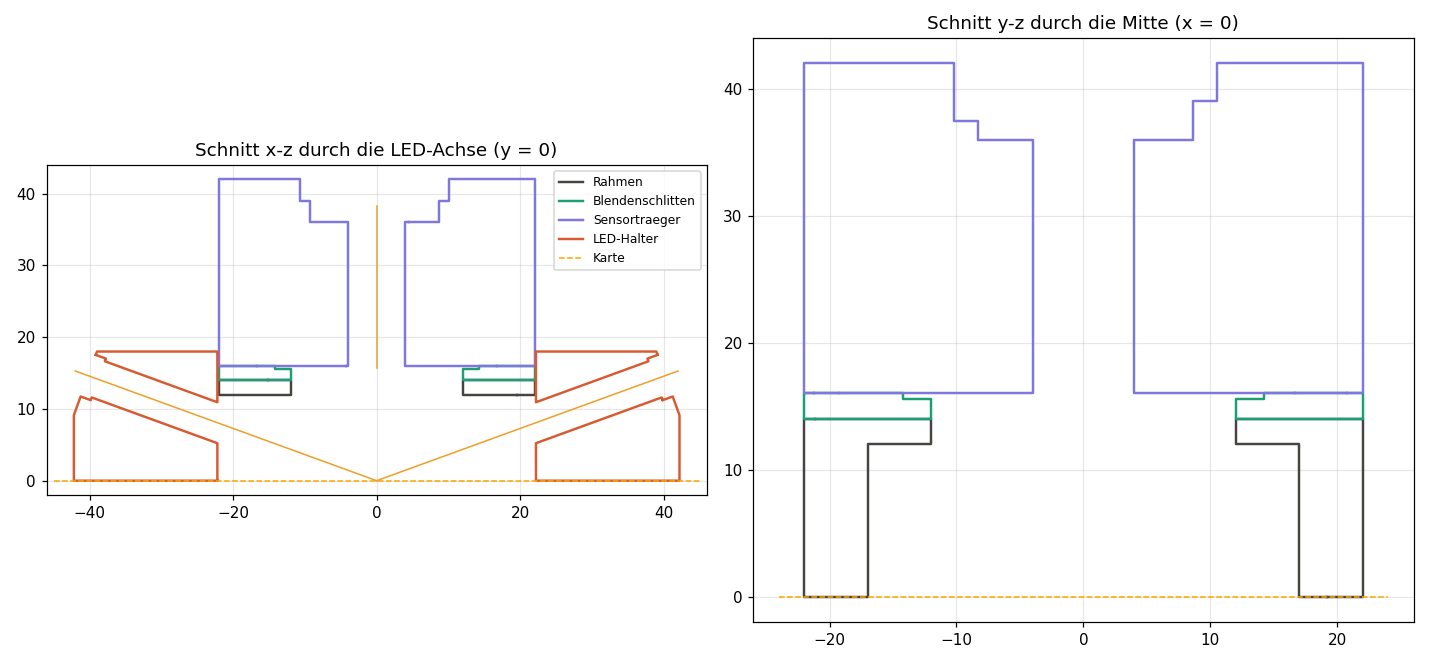
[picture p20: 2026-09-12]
hardware/jig/jig_v5_sections.png

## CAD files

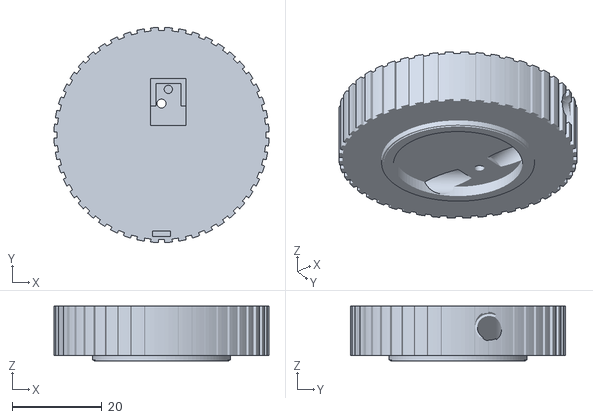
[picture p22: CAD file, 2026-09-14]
hardware/jig/halo_head_rotor.stl
48.0 x 48.0 x 12.2

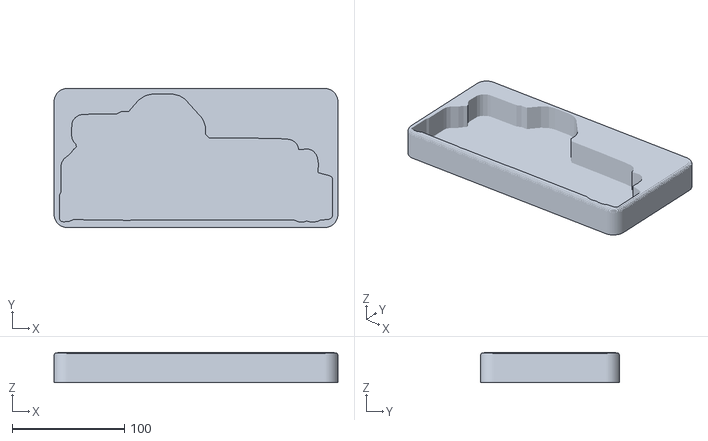
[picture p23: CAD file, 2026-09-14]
hardware/jig/GK1_Mini_stand_v1.stl
253.0 x 124.0 x 27.0

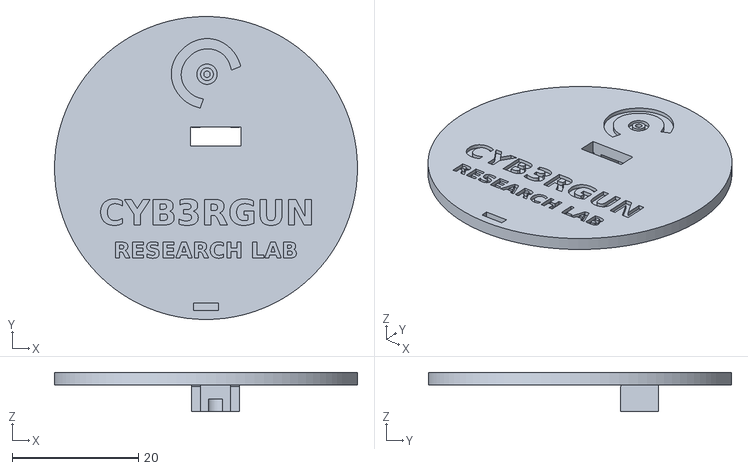
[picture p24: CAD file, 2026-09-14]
hardware/jig/halo_head_lid.stl
48.0 x 48.0 x 6.20

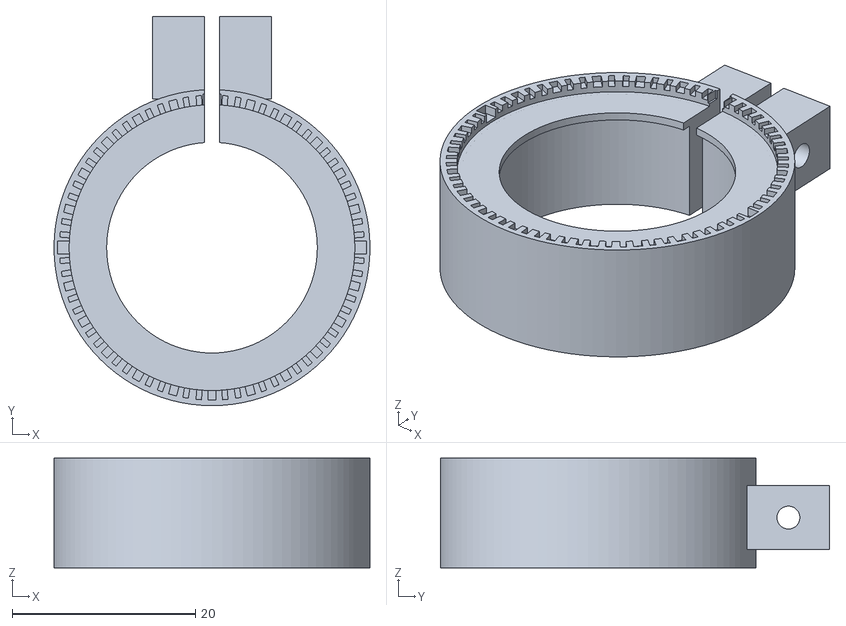
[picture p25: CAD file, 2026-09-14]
hardware/jig/halo_head_collar.stl
34.5 x 42.5 x 12.0

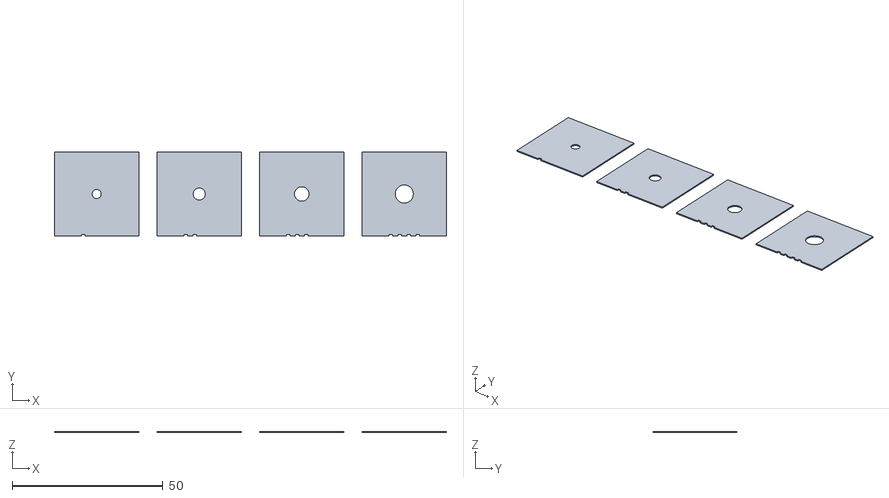
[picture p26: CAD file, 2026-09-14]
hardware/jig/jig_v6_pinhole_plates_large.stl
130.0 x 28.0 x 0.4

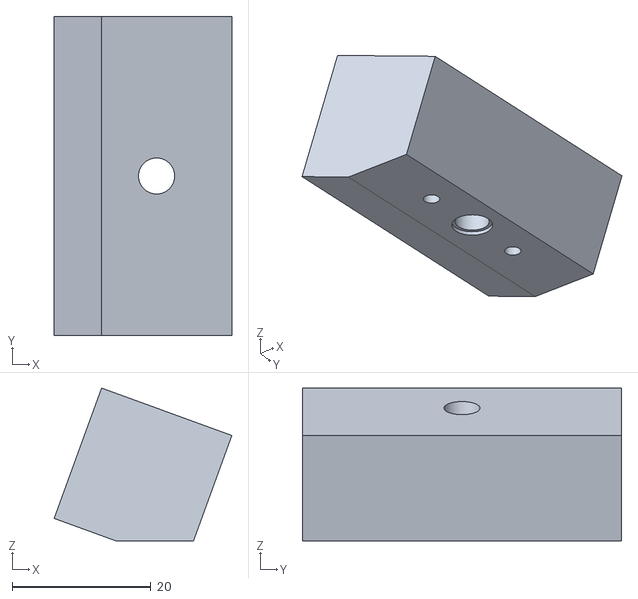
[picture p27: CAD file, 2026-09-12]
hardware/jig/jig_v6_led_holder.stl
25.6 x 46.0 x 22.0

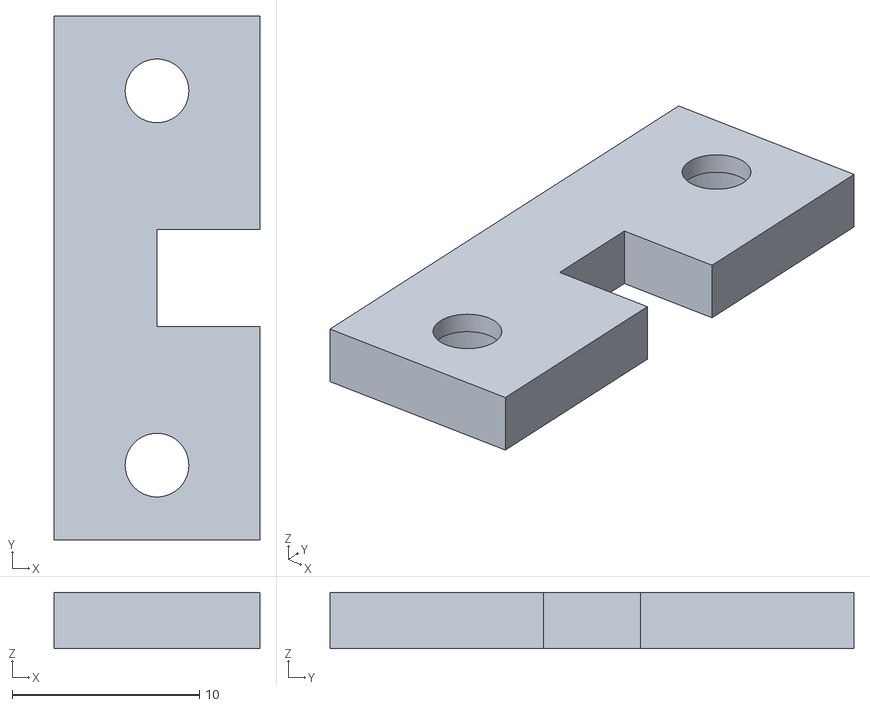
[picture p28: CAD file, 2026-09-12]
hardware/jig/jig_v6_led_cap.stl
11.0 x 28.0 x 3.00

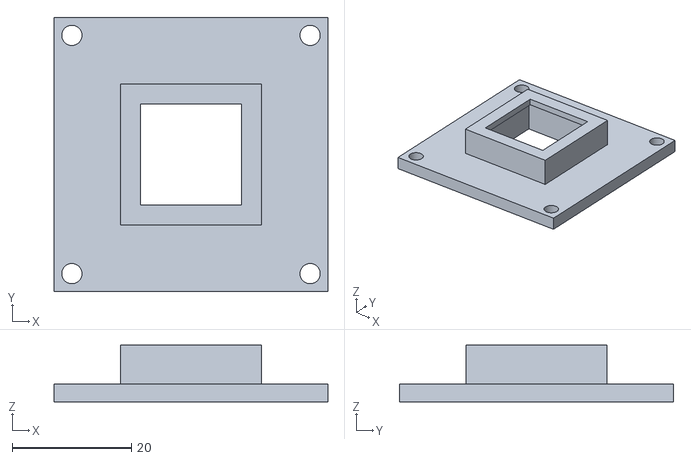
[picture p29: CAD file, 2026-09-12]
hardware/jig/jig_v6_pt_tower.stl
46.0 x 46.0 x 9.50

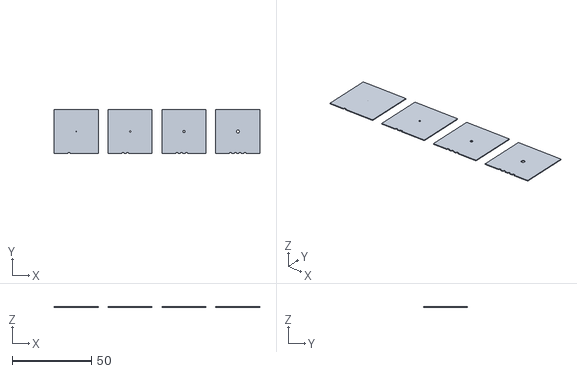
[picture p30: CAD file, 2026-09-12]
hardware/jig/jig_v5_pinhole_plates.stl
130.0 x 28.0 x 0.4

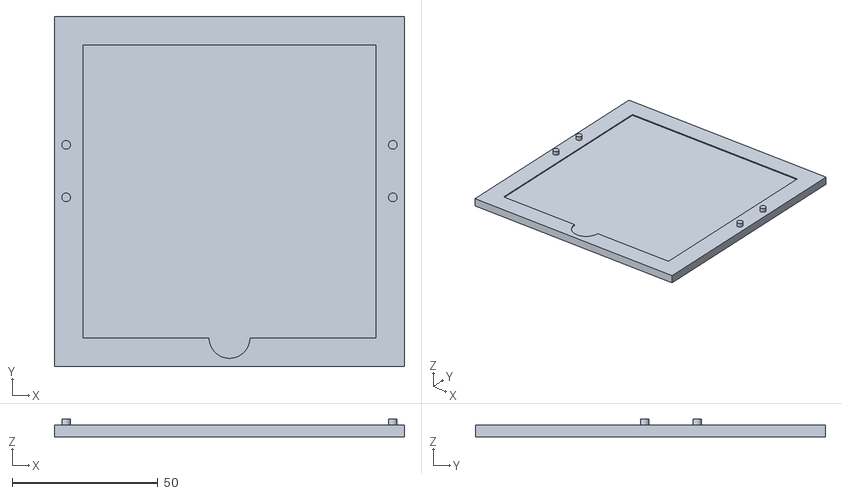
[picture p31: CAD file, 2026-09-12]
hardware/jig/gauge_jig_base.stl
120.0 x 120.0 x 6.00

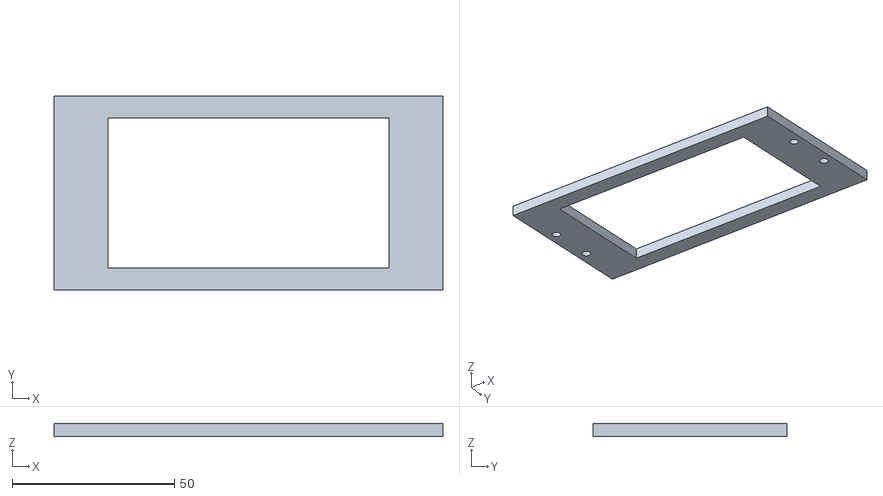
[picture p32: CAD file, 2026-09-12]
hardware/jig/jig_v6_rail.stl
120.0 x 60.0 x 4.00

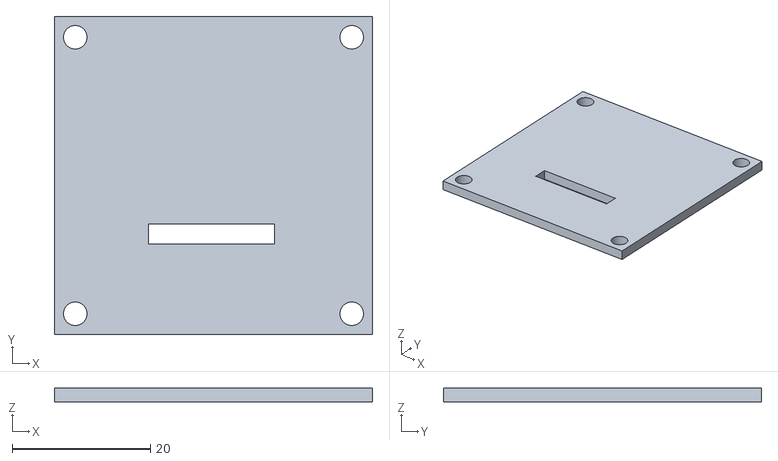
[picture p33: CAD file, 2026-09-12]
hardware/jig/jig_v6_lid_tcs.stl
46.0 x 46.0 x 2.00

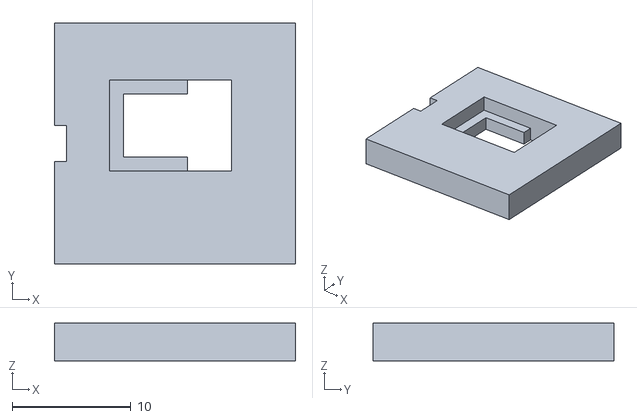
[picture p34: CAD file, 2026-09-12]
hardware/jig/jig_v6_pt19_insert.stl
20.3 x 20.3 x 3.20

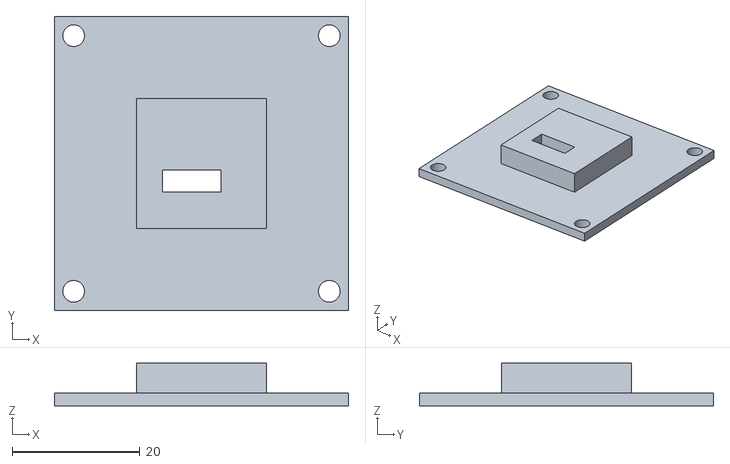
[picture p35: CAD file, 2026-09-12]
hardware/jig/jig_v6_lid_pt19_tower.stl
46.0 x 46.0 x 6.70

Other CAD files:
hardware/jig/jig_v6_lid_pt19.stl
hardware/jig/jig_v6_frame.stl
hardware/jig/jig_v6_carrier.stl

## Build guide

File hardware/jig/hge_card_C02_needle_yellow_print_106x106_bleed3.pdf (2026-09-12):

HGE-C02 needle yellow C0 M28 Y100 K0 | halo-gauge-experiment | Sascha Dämgen

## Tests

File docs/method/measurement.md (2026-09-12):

# Measurement method

How a series is taken, what the numbers mean, and what has to be true for them
to be worth anything.

## The question

Is the reflective contrast between a gauge dial and its needle large enough for
a cheap sensor to tell them apart, and does the choice of wavelength matter.

Go / no-go, set before the first measurement: **SNR of 10 or better** on at
least one channel, where SNR is the difference between the two targets divided
by the combined noise.

## Sensors

| part | what it is for | connection |
|---|---|---|
| TCS34725 | the instrument of the experiment. Four channels, clear, red, green and blue, so it says *which* wavelength the needle swallows | I2C |
| ALS-PT19 | what goes into the product. Broadband, no gain, thirty cents | analog |

Both sit in the same carrier pocket, one at a time, so nothing but the sensor
changes between the two runs. The colour sensor answers why it works, the
phototransistor proves the cheap part is enough.

## Wiring, Heltec WiFi LoRa 32 V2

| part | pin | Heltec | colour |
|---|---|---|---|
| TCS34725 | VIN | 5V | red |
| TCS34725 | GND | GND | black |
| TCS34725 | SCL | 15 | yellow |
| TCS34725 | SDA | 4 | blue |
| TCS34725 | LED | GND | black |
| ALS-PT19 A | + / - / out | 3V3 / GND / 36 | orange / brown / white |
| ALS-PT19 B | + / - / out | 3V3 / GND / 37 | orange / brown / green |
| blue LED | gate of its switch | 22 | violet |
| white LED | gate of its switch | 23 | grey |

The OLED of the Heltec V2 shares the I2C bus on GPIO 4 and 15, with reset on 16
and power through Vext on 21. The firmware handles that.

### Light source

The LEDs are 5 mm with a clear lens, blue around 470 nm and cold white for the
comparison run. They sit in printed holders outside the chamber and shine
through a window in its wall at 20 degrees, so the geometry is 20/0: light in
at twenty degrees, sensor looking straight down. Colour measurement usually
works at 45/0, but under ten millimetres of build height there is no room for
forty-five degrees, and the ring will have the same constraint.

They run from a bench supply at 12 V through the resistor in their lead, about
20 mA, switched low side by a logic level MOSFET on the gate pins above.

**Two things learned the hard way, both in the log:**

An LED lead with an inline resistor sized for 12 V draws half a milliampere at
3.3 V. It lights, and it is useless. Always check the current, not the glow.

Supply matters more than expected. The first series ran off the USB rail and
carried 3.6 % scatter. The same measurement off a linear bench supply carried
0.5 %. The scatter grew with the signal, which is what told us it came from the
light source and not from the sensor.

## Cards

Printed on one printer, on one paper, at 100 % with no scaling. Every sheet
carries a ruler so a wrongly scaled print is obvious before it is measured.

| card | what it is |
|---|---|
| HGE-C01 | white, the dial reference. No ink at all, the paper is the reference |
| HGE-C02 | the needle colour, RGB 252 / 184 / 3, sampled from the gauge artwork |
| HGE-D01.. | dial cards with the needle at each position, generated by `tools/make_cards.py` |

Printer ink is not needle lacquer. These cards prove the method is viable. The
calibration happens on the real gauge.

### Scale and the aperture that goes with it

The needle at the measuring radius is thinner than it looks: on a 20 mm dial
with the sensor at 7 mm it is about 0.55 mm wide. To see the shape of the
shadow at all, the dial cards are printed magnified.

At any scale other than 1:1 two things have to scale with it, or the test
flatters itself:

- **the aperture.** A 1.6 mm sensor element at 3:1 is 4.8 mm. Measuring a
  magnified needle through a 1 mm hole is looking closer than the real part
  ever will.
- **the position of the dial.** The sensor sits at a fixed 7 mm from the card
  centre in this fixture. At 3:1 the measuring radius is 21 mm, so the card
  generator shifts the dial 14 mm down and the fixed sensor lands exactly on
  the measuring radius. The card prints a dashed mark at that spot so it can be
  checked by eye.

## Procedure

1. Card in the pocket of the base plate, rail on the pegs, frame on the card,
   LED holders either side, slide with the aperture card, carrier with the
   sensor, four screws.
2. Start the software, pick the campaign in the setup view. The aperture field
   and the needle position go into every file name and every record.
3. Press White, confirm when the fixture is closed and your hand is off it. The
   probe takes N samples with the emitter on and N with it off.
4. Swap to the yellow card, press Yellow.
5. Press Report.

For a needle sweep the same thing runs against the position list: the software
asks for the card of the next position, you confirm, it measures, ticks that
position off and moves to the next.

## Evaluation

Per channel, with `on` and `off` meaning emitter on and emitter off:

```
signal   = mean(on) - mean(off)
noise    = sqrt(sd(on)^2 + sd(off)^2)
contrast = (signal_white - signal_yellow) / signal_white
SNR      = |signal_white - signal_yellow| / sqrt(noise_white^2 + noise_yellow^2)
```

The on-minus-off difference removes constant ambient light. It does not remove
flicker, so room lighting stays off during a series.

**One honest caveat that belongs with every phototransistor number.** The ESP32
analog input has a floor around 142 mV and reads everything below it as the
same value. When the emitter-off reading sits on that floor, the difference is
not trustworthy and the ratio of the absolute on-values is the honest figure.
That is also the reason the sensor ring will not hang straight off an ESP32
input: it needs an external converter or a gain stage. That was found here,
before the board was laid out, which is what this fixture is for.

## Raw data

Every finished series is written three ways into `docs/log/data/`: a readable
text record, the raw JSON from the firmware, and a row in the SQLite database.
Every serial line, parseable or not, also goes into a dated session log, which
is the fallback if anything else fails.

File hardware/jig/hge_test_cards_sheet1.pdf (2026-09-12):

# HALO GAUGE EXPERIMENT

### github.com/saschadaemgen/halo-gauge-experiment

### open research | optical needle readout for 20 mm gauges | 2026

## Sascha Dämgen

# halo-gauge-experiment

## Test cards, sheet 1: full colour references for the contrast measurement

PRINT AT 100 %, NO SCALING, A4. Check the ruler at the bottom after printing.

## HGE-C01 WHITE

reference for the dial face. Paper white, no ink. Cut on the grey line.

HGE-C01

## HGE-C02 NEEDLE YELLOW

reference for the needle. RGB 252 / 184 / 3, hex #FCB803, sampled from the gauge artwork.

HGE-C02

0 | 10 | 20 | 30 | 40 | 50 | 60 | 70 | 80 | 90 | 100

100 mm check ruler. Steel rule: 100.0 +/- 0.5 mm is fine. 97 mm means the driver scaled the page.

hardware/cards/hge_test_cards_sheet1.pdf Cards are 100 x 100 mm and fit the pocket of the jig base plate (100.4 mm).
Print both cards on the same printer and paper. Printer ink is not needle lacquer: these cards prove viability, calibration happens on the real gauge.

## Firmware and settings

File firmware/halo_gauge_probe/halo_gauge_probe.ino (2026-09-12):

/*
 * ============================================================================
 *  HALO GAUGE PROBE
 *  Stage 0 + 1: Contrast and SNR characterization
 * ----------------------------------------------------------------------------
 *  Board       : Heltec WiFi LoRa 32 V2 (ESP32, 0.96 inch SSD1306 OLED)
 *  Sensors     : TCS34725 RGB color sensor (CJMCU clone, I2C address 0x29)
 *                2x ALS-PT19 phototransistor breakout (analog out)
 *  Light       : TCS34725 onboard white LED, switched via its LED pin
 *                optional external blue LED (~470 nm) via 220 ohm
 *  Purpose     : Quantify the optical contrast between a white gauge dial
 *                and a light-yellow needle. Decides whether a reflective
 *                sensor arc is viable before any PCB is manufactured.
 *  Method      : LED ON / LED OFF differential measurement per channel,
 *                N samples each, mean and standard deviation, then
 *                contrast = (white - yellow) / white and
 *                SNR = |white - yellow| / combined noise.
 *  Go / No-Go  : SNR >= 10 on at least one channel.
 *
 *  Link        : USB 115200 baud, and TCP port 3333 when WiFi is configured
 *  Serial      : 115200 baud, single-key commands, see 'h'. 'j' switches to
 *                JSON lines for the lab software (one object per line).
 * ============================================================================
 */

#include <WiFi.h>
#include <ArduinoOTA.h>
#include <Wire.h>
#include <Adafruit_TCS34725.h>
#include <Adafruit_GFX.h>
#include <Adafruit_SSD1306.h>
#include <math.h>

// ---------------------------------------------------------------------------
// Network. Fill in your own credentials. Leave WIFI_SSID empty to stay on USB
// only. With WiFi on, the board also listens on port 3333 and speaks exactly
// the same protocol there, so the USB cable can be pulled off the PC.
// ---------------------------------------------------------------------------
static const char* WIFI_SSID = "";
static const char* WIFI_PASS = "";
static const uint16_t NET_PORT = 3333;

// ---------------------------------------------------------------------------
// Pins, Heltec WiFi LoRa 32 V2
// ---------------------------------------------------------------------------
static const int PIN_I2C_SDA  = 4;    // shared: OLED + TCS34725
static const int PIN_I2C_SCL  = 15;   // shared: OLED + TCS34725
static const int PIN_OLED_RST = 16;
static const int PIN_VEXT     = 21;   // LOW enables Vext, powers the OLED
static const int PIN_TCS_LED  = 23;   // TCS34725 board pin "LED", HIGH = on
static const int PIN_BLUE_LED = 22;   // external blue LED, anode via 220 ohm
static const int PIN_PT19_A   = 36;   // ALS-PT19 board A, pin "out"
static const int PIN_PT19_B   = 37;   // ALS-PT19 board B, pin "out"

// ---------------------------------------------------------------------------
// Measurement parameters
// ---------------------------------------------------------------------------
static int            sampleCount    = 50;      // per series (on and off each), key n
static const int      ADC_OVERSAMPLE = 16;      // ADC reads averaged per sample
static const uint16_t SAT_LIMIT      = 65000;   // TCS34725 clear channel limit
static const int      SETTLE_MS      = 250;     // after switching the light
static const double   SNR_GO         = 10.0;

// ---------------------------------------------------------------------------
// Channels
// ---------------------------------------------------------------------------
enum Channel { CH_C = 0, CH_R, CH_G, CH_B, CH_PTA, CH_PTB, CH_COUNT };
static const char* CH_NAME[CH_COUNT] = { "C", "R", "G", "B", "PT-A", "PT-B" };
static const char* CH_UNIT[CH_COUNT] = { "cnt", "cnt", "cnt", "cnt", "mV", "mV" };

enum Illum  { ILLUM_WHITE = 0, ILLUM_BLUE = 1, ILLUM_COUNT };
enum Target { TGT_WHITE = 0, TGT_YELLOW = 1, TGT_COUNT = 2, TGT_POINT = 2 };
static const char* ILLUM_NAME[ILLUM_COUNT] = { "WHITE LED", "BLUE LED" };
static const char* TGT_NAME[3]            = { "WHITE (dial)", "YELLOW (needle)", "POINT" };

struct Stats {
  double mean[CH_COUNT];
  double sd[CH_COUNT];
};

struct Series {
  bool   valid;
  bool   saturated;
  Stats  on;
  Stats  off;
  double signal[CH_COUNT];   // on.mean - off.mean, ambient removed
  double noise[CH_COUNT];    // sqrt(on.sd^2 + off.sd^2)
};

static Series results[ILLUM_COUNT][TGT_COUNT];

// ---------------------------------------------------------------------------
// Gain table for the TCS34725
// ---------------------------------------------------------------------------
static const tcs34725Gain_t GAIN_VALUE[4] = {
  TCS34725_GAIN_1X, TCS34725_GAIN_4X, TCS34725_GAIN_16X, TCS34725_GAIN_60X
};
static const char* GAIN_NAME[4] = { "1x", "4x", "16x", "60x" };
static int gainIndex = 2;   // start at 16x

// ---------------------------------------------------------------------------
// Globals
// ---------------------------------------------------------------------------
// Everything the probe prints goes to USB and, when connected, to the network
// client as well, so both look identical.
class Tee : public Print {
public:
  WiFiClient client;
  size_t write(uint8_t c) override {
    Serial.write(c);
    if (client && client.connected()) client.write(c);
    return 1;
  }
  size_t write(const uint8_t* buf, size_t n) override {
    Serial.write(buf, n);
    if (client && client.connected()) client.write(buf, n);
    return n;
  }
};
static Tee out;
static WiFiServer netServer(NET_PORT);
static bool netUp = false;

Adafruit_TCS34725 tcs(TCS34725_INTEGRATIONTIME_154MS, TCS34725_GAIN_16X);
Adafruit_SSD1306  oled(128, 64, &Wire, PIN_OLED_RST);

static Illum         illum   = ILLUM_BLUE;   // start with the blue LED, white is optional
static bool          liveOn  = true;
static bool          oledOk  = false;
static bool          tcsOk   = false;   // colour sensor is optional, phototransistors alone are fine
static bool          jsonOn  = false;   // machine readable output for the lab software, toggled with j
static const char*   FW_VERSION = "probe-0.5";
static unsigned long lastLive = 0;

// ---------------------------------------------------------------------------
// Forward declarations for the display helpers used inside the sampling loop
// ---------------------------------------------------------------------------
static void centeredText(const char* txt, int size, int y);
static void oledArming();
static void oledCountdown();
static void oledRun(Target tgt, bool ledOn, int n, double value, const char* name,
                    const char* unit);

// ---------------------------------------------------------------------------
// Light control
// ---------------------------------------------------------------------------
static void setLight(Illum which, bool on) {
  digitalWrite(PIN_TCS_LED,  (on && which == ILLUM_WHITE) ? HIGH : LOW);
  digitalWrite(PIN_BLUE_LED, (on && which == ILLUM_BLUE)  ? HIGH : LOW);
}

static void lightsOff() {
  digitalWrite(PIN_TCS_LED,  LOW);
  digitalWrite(PIN_BLUE_LED, LOW);
}

// ---------------------------------------------------------------------------
// One raw sample across all channels. Returns true if the clear channel
// is saturated.
// ---------------------------------------------------------------------------
static bool readSample(double out[CH_COUNT]) {
  uint16_t r = 0, g = 0, b = 0, c = 0;
  if (tcsOk) {
    tcs.getRawData(&r, &g, &b, &c);   // blocks for one integration time
  } else {
    delay(154);                       // keep the sample timing without the sensor
  }

  uint32_t accA = 0, accB = 0;
  for (int i = 0; i < ADC_OVERSAMPLE; i++) {
    accA += analogReadMilliVolts(PIN_PT19_A);
    accB += analogReadMilliVolts(PIN_PT19_B);
  }

  out[CH_C]   = c;
  out[CH_R]   = r;
  out[CH_G]   = g;
  out[CH_B]   = b;
  out[CH_PTA] = (double)accA / ADC_OVERSAMPLE;
  out[CH_PTB] = (double)accB / ADC_OVERSAMPLE;

  return c >= SAT_LIMIT;
}

// ---------------------------------------------------------------------------
// Collect one series of sampleCount with the light in the given state.
// ---------------------------------------------------------------------------
static bool collect(Stats& st, bool lightOn, Target tgt) {
  double sum[CH_COUNT]   = {0};
  double sumSq[CH_COUNT] = {0};
  bool   saturated = false;

  setLight(illum, lightOn);
  delay(SETTLE_MS);

  for (int n = 0; n < sampleCount; n++) {
    double s[CH_COUNT];
    if (readSample(s)) saturated = true;
    if (jsonOn) jsonSample(tgt, lightOn, n, s);
    if ((n % 2) == 0) {
      bool colour = s[CH_C] > 5.0;
      oledRun(tgt, lightOn, (lightOn ? 0 : sampleCount) + n,
              colour ? s[CH_C] : s[CH_PTA], colour ? "C" : "PT-A", colour ? "cnt" : "mV");
    }
    for (int ch = 0; ch < CH_COUNT; ch++) {
      sum[ch]   += s[ch];
      sumSq[ch] += s[ch] * s[ch];
    }
    if ((n % 10) == 9 && !jsonOn) out.print('.');
  }
  lightsOff();

  for (int ch = 0; ch < CH_COUNT; ch++) {
    st.mean[ch] = sum[ch] / sampleCount;
    double var  = (sumSq[ch] - sampleCount * st.mean[ch] * st.mean[ch]) / (sampleCount - 1);
    st.sd[ch]   = var > 0 ? sqrt(var) : 0.0;
  }
  return saturated;
}

// ---------------------------------------------------------------------------
// OLED helpers
// ---------------------------------------------------------------------------
static void oledMessage(const char* line1, const char* line2) {
  if (!oledOk) return;
  oled.clearDisplay();
  oled.setTextSize(1);
  oled.setCursor(0, 0);
  oled.println("HALO GAUGE PROBE");
  oled.setTextSize(2);
  oled.setCursor(0, 20);
  oled.println(line1);
  oled.setTextSize(1);
  oled.setCursor(0, 50);
  oled.println(line2);
  oled.display();
}

// ---------------------------------------------------------------------------
// Display animation. The SSD1306 is 128 x 64 and one bit deep, so there is no
// fading: smoothness has to come from geometry that moves every frame. All
// sequences run at 40 frames per second off millis(), never off delay chains,
// and every screen change is a wipe rather than a cut.
// ---------------------------------------------------------------------------
static const int SCR_W = 128, SCR_H = 64;
static const uint32_t FRAME_MS = 25;

static float easeOut(float t) { return 1.0f - (1.0f - t) * (1.0f - t); }
static float easeInOut(float t) { return t < 0.5f ? 2 * t * t : 1 - 2 * (1 - t) * (1 - t); }

// Arc drawn from short segments, used as a sweeping progress ring.
static void oledArc(int cx, int cy, int r, float a0, float a1, int thickness) {
  int steps = max(3, (int)(fabsf(a1 - a0) * r / 3.0f));
  for (int i = 0; i < steps; i++) {
    float a = a0 + (a1 - a0) * i / (float)steps;
    float b = a0 + (a1 - a0) * (i + 1) / (float)steps;
    for (int t = 0; t < thickness; t++) {
      oled.drawLine(cx + cosf(a) * (r - t), cy + sinf(a) * (r - t),
                    cx + cosf(b) * (r - t), cy + sinf(b) * (r - t), SSD1306_WHITE);
    }
  }
}

static void centeredText(const char* txt, int size, int y) {
  int w = strlen(txt) * 6 * size;
  oled.setTextSize(size);
  oled.setCursor((SCR_W - w) / 2, y);
  oled.print(txt);
}

// Iris wipe: two shutters close over the current picture, then open on the next.
static void oledWipeOut(uint32_t ms) {
  if (!oledOk) return;
  uint32_t t0 = millis();
  for (;;) {
    float t = (millis() - t0) / (float)ms;
    if (t >= 1.0f) break;
    int h = (int)(easeInOut(t) * (SCR_H / 2 + 1));
    oled.fillRect(0, 0, SCR_W, h, SSD1306_BLACK);
    oled.fillRect(0, SCR_H - h, SCR_W, h, SSD1306_BLACK);
    oled.drawFastHLine(0, h, SCR_W, SSD1306_WHITE);
    oled.drawFastHLine(0, SCR_H - h - 1, SCR_W, SSD1306_WHITE);
    oled.display();
    delay(FRAME_MS);
  }
  oled.clearDisplay();
  oled.display();
}

// One boot line sliding in from the right, then settling.
static void oledSlideLine(const char* txt, int y, uint32_t ms) {
  if (!oledOk) return;
  uint32_t t0 = millis();
  for (;;) {
    float t = (millis() - t0) / (float)ms;
    if (t >= 1.0f) break;
    int x = (int)((1.0f - easeOut(t)) * SCR_W);
    oled.fillRect(0, y, SCR_W, 10, SSD1306_BLACK);
    oled.setTextSize(1);
    oled.setCursor(2 + x, y);
    oled.print(txt);
    oled.display();
    delay(FRAME_MS);
  }
  oled.fillRect(0, y, SCR_W, 10, SSD1306_BLACK);
  oled.setTextSize(1);
  oled.setCursor(2, y);
  oled.print(txt);
  oled.display();
}

// Arming sequence, shown once after boot. Every line is a real setting.
static void oledArming() {
  if (!oledOk) return;
  oled.clearDisplay();
  centeredText("HALO PROBE", 1, 0);
  oled.drawFastHLine(0, 10, SCR_W, SSD1306_WHITE);
  oled.display();
  char l1[24], l2[24];
  snprintf(l1, sizeof(l1), "BEAM 470nm ARMED");
  snprintf(l2, sizeof(l2), "INTEGRATION 154ms");
  oledSlideLine(l1, 16, 260);
  oledSlideLine("DIFFERENTIAL MODE", 28, 260);
  oledSlideLine(l2, 40, 260);
  oledSlideLine(tcsOk ? "RGBC + PT LINKED" : "PT CHANNELS LINKED", 52, 260);
  delay(500);
  oledWipeOut(220);
}

// Countdown. The digit sits inside a ring that sweeps a full turn every second
// while the iris contracts, so nothing jumps between steps.
static void oledCountdown() {
  if (!oledOk) return;
  const int cx = SCR_W / 2, cy = 34;
  for (int i = 3; i >= 1; i--) {
    uint32_t t0 = millis();
    for (;;) {
      float t = (millis() - t0) / 1000.0f;
      if (t >= 1.0f) break;
      oled.clearDisplay();
      oled.setTextColor(SSD1306_WHITE);
      oled.setTextSize(1);
      oled.setCursor(0, 0);
      oled.print("ALIGNING");
      oled.setCursor(74, 0);
      oled.print("HOLD STILL");
      oled.drawFastHLine(0, 10, SCR_W, SSD1306_WHITE);

      int outer = 28 - (3 - i) * 2;                    // iris steps in per second
      int r = outer - (int)(easeInOut(t) * 3.0f);      // and breathes within it
      oledArc(cx, cy, r, -1.5708f, -1.5708f + 6.2832f * t, 2);
      oled.drawCircle(cx, cy, r - 6, SSD1306_WHITE);

      char d[2] = { (char)('0' + i), 0 };
      oled.setTextSize(3);
      oled.setCursor(cx - 8, cy - 11);
      oled.print(d);
      oled.display();
      delay(FRAME_MS);
    }
  }
  // the ring collapses into the word, no cut
  uint32_t t0 = millis();
  for (;;) {
    float t = (millis() - t0) / 420.0f;
    if (t >= 1.0f) break;
    oled.clearDisplay();
    oled.setTextSize(1);
    oled.setCursor(0, 0);
    oled.print("ALIGNING");
    oled.drawFastHLine(0, 10, SCR_W, SSD1306_WHITE);
    int r = (int)(24 - easeOut(t) * 22);
    oledArc(cx, cy, max(r, 2), -1.5708f, 4.7124f, 2);
    if (t > 0.45f) centeredText("MEASURING", 1, cy - 4);
    oled.display();
    delay(FRAME_MS);
  }
}

// Live screen while a series runs. The number is damped so it does not jitter,
// the bar grows continuously and a scan dot travels along it.
static void oledRun(Target tgt, bool ledOn, int n, double value, const char* name,
                    const char* unit) {
  if (!oledOk) return;
  static double shown = 0.0;
  static int lastN = -1;
  if (n < lastN) shown = value;              // new series, start where we are
  lastN = n;
  shown += (value - shown) * 0.35;           // first order damping

  oled.clearDisplay();
  oled.setTextColor(SSD1306_WHITE);
  oled.setTextSize(1);
  oled.setCursor(0, 0);
  oled.print(tgt == TGT_WHITE ? "WHITE" : (tgt == TGT_YELLOW ? "YELLOW" : "POINT"));
  oled.setCursor(62, 0);
  oled.print(ledOn ? "BEAM ON" : "AMBIENT");
  if (ledOn) oled.fillCircle(122, 3, 3, SSD1306_WHITE);
  else       oled.drawCircle(122, 3, 3, SSD1306_WHITE);
  oled.drawFastHLine(0, 10, SCR_W, SSD1306_WHITE);

  char buf[16];
  snprintf(buf, sizeof(buf), "%ld", (long)(shown + 0.5));
  oled.setTextSize(3);
  oled.setCursor(2, 18);
  oled.print(buf);
  oled.setTextSize(1);
  oled.setCursor(2 + (int)strlen(buf) * 18 + 4, 32);
  oled.print(unit);

  oled.setTextSize(1);
  oled.setCursor(2, 44);
  oled.print(name);
  snprintf(buf, sizeof(buf), "%d/%d", n, sampleCount * 2);
  oled.setCursor(SCR_W - (int)strlen(buf) * 6 - 2, 44);
  oled.print(buf);

  int total = sampleCount * 2;
  int w = (n * (SCR_W - 4)) / max(total, 1);
  oled.drawRect(0, 54, SCR_W, 9, SSD1306_WHITE);
  oled.fillRect(2, 56, w, 5, SSD1306_WHITE);
  int dot = 2 + w;                            // scan dot rides the front edge
  if (dot < SCR_W - 3) {
    oled.drawFastVLine(dot, 55, 7, SSD1306_WHITE);
    oled.drawFastVLine(dot + 1, 55, 7, SSD1306_WHITE);
  }
  oled.display();
}

static void oledLive(const double s[CH_COUNT], bool sat) {
  if (!oledOk) return;
  oled.clearDisplay();
  oled.setTextSize(1);
  oled.setCursor(0, 0);
  oled.print("PROBE ");
  oled.print(ILLUM_NAME[illum]);
  oled.print(" ");
  oled.print(GAIN_NAME[gainIndex]);
  oled.setCursor(0, 14);
  oled.print("C "); oled.print((int)s[CH_C]);
  if (sat) oled.print(" SAT");
  oled.setCursor(0, 24);
  oled.print("R "); oled.print((int)s[CH_R]);
  oled.print("  G "); oled.print((int)s[CH_G]);
  oled.setCursor(0, 34);
  oled.print("B "); oled.print((int)s[CH_B]);
  oled.setCursor(0, 46);
  oled.print("PT-A "); oled.print((int)s[CH_PTA]); oled.print(" mV");
  oled.setCursor(0, 56);
  oled.print("PT-B "); oled.print((int)s[CH_PTB]); oled.print(" mV");
  oled.display();
}

// ---------------------------------------------------------------------------
// JSON output for the lab software (one object per line, toggled with j)
// ---------------------------------------------------------------------------
static const char* lightName(Illum il)   { return il == ILLUM_WHITE ? "white" : "blue"; }
static const char* targetName(Target t)  {
  return t == TGT_WHITE ? "white" : (t == TGT_YELLOW ? "yellow" : "point");
}

static void jsonSampleValues(char* buf, size_t len, const double s[CH_COUNT]) {
  snprintf(buf, len, "\"c\":%.0f,\"r\":%.0f,\"g\":%.0f,\"b\":%.0f,\"pta\":%.1f,\"ptb\":%.1f",
           s[CH_C], s[CH_R], s[CH_G], s[CH_B], s[CH_PTA], s[CH_PTB]);
}

static void jsonHello() {
  out.printf("{\"type\":\"hello\",\"fw\":\"%s\",\"tcs\":%d,\"oled\":%d,\"light\":\"%s\",\"gain\":\"%s\",\"samples\":%d}\n",
                FW_VERSION, tcsOk ? 1 : 0, oledOk ? 1 : 0, lightName(illum), GAIN_NAME[gainIndex], sampleCount);
}

static void jsonAck(const char* cmd) {
  out.printf("{\"type\":\"ack\",\"cmd\":\"%s\",\"light\":\"%s\",\"gain\":\"%s\",\"samples\":%d,\"live\":%d}\n",
                cmd, lightName(illum), GAIN_NAME[gainIndex], sampleCount, liveOn ? 1 : 0);
}

static void jsonLive(const double s[CH_COUNT], bool sat) {
  char v[128]; jsonSampleValues(v, sizeof(v), s);
  out.printf("{\"type\":\"live\",\"t\":%lu,%s,\"sat\":%d,\"light\":\"%s\",\"gain\":\"%s\"}\n",
                (unsigned long)millis(), v, sat ? 1 : 0, lightName(illum), GAIN_NAME[gainIndex]);
}

static void jsonSample(Target tgt, bool ledOn, int n, const double s[CH_COUNT]) {
  char v[128]; jsonSampleValues(v, sizeof(v), s);
  out.printf("{\"type\":\"sample\",\"target\":\"%s\",\"led\":%d,\"n\":%d,%s}\n",
                targetName(tgt), ledOn ? 1 : 0, n, v);
}

static void jsonStats(const char* key, const Stats& st) {
  out.printf("\"%s\":{", key);
  for (int ch = 0; ch < CH_COUNT; ch++) {
    out.printf("%s\"%s\":[%.2f,%.2f]", ch ? "," : "", CH_NAME[ch], st.mean[ch], st.sd[ch]);
  }
  out.print("}");
}

static void jsonSeries(Target tgt, const Series& res) {
  out.printf("{\"type\":\"series\",\"target\":\"%s\",\"light\":\"%s\",\"gain\":\"%s\",\"samples\":%d,\"saturated\":%d,",
                targetName(tgt), lightName(illum), GAIN_NAME[gainIndex], sampleCount, res.saturated ? 1 : 0);
  jsonStats("on", res.on); out.print(","); jsonStats("off", res.off);
  out.print(",\"signal\":{");
  for (int ch = 0; ch < CH_COUNT; ch++) out.printf("%s\"%s\":%.2f", ch ? "," : "", CH_NAME[ch], res.signal[ch]);
  out.print("},\"noise\":{");
  for (int ch = 0; ch < CH_COUNT; ch++) out.printf("%s\"%s\":%.2f", ch ? "," : "", CH_NAME[ch], res.noise[ch]);
  out.println("}}");
}

// ---------------------------------------------------------------------------
// Run one full series for a target under the current illumination
// ---------------------------------------------------------------------------
static Series pointSeries;   // a free measurement, not part of the white/yellow pair
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
void loop() {
  if (netUp) {
    ArduinoOTA.handle();
    WiFiClient incoming = netServer.available();
    if (incoming) {
      if (out.client && out.client.connected()) out.client.stop();
      out.client = incoming;
      out.client.setNoDelay(true);
      if (jsonOn) jsonHello();
    }
  }

  while (Serial.available()) {
    handleCommand((char)Serial.read());
  }
  while (out.client && out.client.available()) {
    handleCommand((char)out.client.read());
  }

  if (liveOn && millis() - lastLive > 400) {
    lastLive = millis();
    double s[CH_COUNT];
    bool sat = readSample(s);
    oledLive(s, sat);
    if (jsonOn) jsonLive(s, sat);
  }
}

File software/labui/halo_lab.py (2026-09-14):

#!/usr/bin/env python3
"""
HALO LAB, measurement front end for the halo-gauge-experiment probe.

Reads the probe firmware (probe-0.2) over USB, streams every object to the
browser, and records each finished series and report to disk.

Dependencies: pyserial. Everything else is the Python standard library.

    python3 halo_lab.py --list
    python3 halo_lab.py --port /dev/ttyUSB0
    python3 halo_lab.py --simulate          # no hardware, fake data

Then open http://127.0.0.1:8760
"""

import argparse
import json
import os
import queue
import math
import random
import shutil
import subprocess
import sys
import threading
import time
from datetime import datetime
from http.server import BaseHTTPRequestHandler, ThreadingHTTPServer

sys.path.insert(0, os.path.dirname(os.path.abspath(__file__)))
from db import Store

HERE = os.path.dirname(os.path.abspath(__file__))
STATIC = os.path.join(HERE, "static")
REPO = os.path.abspath(os.path.join(HERE, "..", ".."))

CHANNELS = ["C", "R", "G", "B", "PT-A", "PT-B"]
UNITS = {"C": "cnt", "R": "cnt", "G": "cnt", "B": "cnt", "PT-A": "mV", "PT-B": "mV"}


# ---------------------------------------------------------------- hub

class Hub:
    """Fans out messages to every connected browser."""

    def __init__(self):
        self.lock = threading.Lock()
        self.clients = []
        self.last_state = {}

    def subscribe(self):
        q = queue.Queue(maxsize=2000)
        with self.lock:
            self.clients.append(q)
        return q

    def unsubscribe(self, q):
        with self.lock:
            if q in self.clients:
                self.clients.remove(q)

    def publish(self, obj):
        if obj.get("type") in ("hello", "ack"):
            self.last_state.update({k: obj[k] for k in ("light", "gain", "fw", "tcs") if k in obj})
        line = json.dumps(obj, separators=(",", ":"))
        with self.lock:
            dead = []
            for q in self.clients:
                try:
                    q.put_nowait(line)
                except queue.Full:
                    dead.append(q)
            for q in dead:
                self.clients.remove(q)


# ---------------------------------------------------------------- recorder

class Recorder:
    """Writes the raw session log and one txt plus one json file per result."""

    def __init__(self, data_dir, image_dir, store=None):
        self.store = store
        self.session_id = None
        self.data_dir = data_dir
        self.image_dir = image_dir
        os.makedirs(self.data_dir, exist_ok=True)
        os.makedirs(self.image_dir, exist_ok=True)
        self.meta = {"aperture": "none", "note": "", "operator": "", "label": ""}
        self.last_stem = None
        self.lock = threading.Lock()

    def _session_path(self):
        return os.path.join(self.data_dir, "session_%s.log" % datetime.now().strftime("%Y-%m-%d"))

    def raw(self, line):
        stamp = datetime.now().strftime("%H:%M:%S.%f")[:-3]
        with self.lock:
            with open(self._session_path(), "a", encoding="utf-8") as f:
                f.write("%s  %s\n" % (stamp, line.rstrip("\r\n")))

    def _slug(self, text, default):
        out = "".join(c.lower() if c.isalnum() else "-" for c in (text or "").strip())
        while "--" in out:
            out = out.replace("--", "-")
        out = out.strip("-")
        return out or default

    def _header(self, obj, kind):
        now = datetime.now()
        lines = [
            "# halo-gauge-experiment, %s" % kind,
            "# date      : %s" % now.strftime("%Y-%m-%d %H:%M:%S"),
            "# firmware  : %s" % self.meta.get("fw", "unknown"),
            "# light     : %s" % obj.get("light", "?"),
            "# gain      : %s" % obj.get("gain", "n/a"),
            "# aperture  : %s" % self.meta.get("aperture", "none"),
            "# samples   : %s" % obj.get("samples", "n/a"),
        ]
        if self.meta.get("operator"):
            lines.append("# operator  : %s" % self.meta["operator"])
        if self.meta.get("note"):
            lines.append("# note      : %s" % self.meta["note"])
        return lines

    def series(self, obj):
        if obj.get("target") == "point" and self.meta.get("label"):
            obj["label"] = self.meta["label"]
        stem = "%s_%s_%s_%s_%s" % (
            datetime.now().strftime("%Y-%m-%d_%H%M"),
            self._slug(obj.get("label") or obj.get("target"), "target"),
            self._slug(obj.get("light"), "light"),
            self._slug(obj.get("gain"), "gain"),
            self._slug(self.meta.get("aperture"), "none"),
        )
        self.last_stem = stem
        body = list(self._header(obj, "series"))
        body.append("")
        body.append("      ch     on.mean   on.sd   off.mean  off.sd   signal   noise")
        for ch in CHANNELS:
            on = obj.get("on", {}).get(ch, [0, 0])
            off = obj.get("off", {}).get(ch, [0, 0])
            body.append("      %-5s %9.1f %7.2f %9.1f %7.2f %8.1f %7.2f %s" % (
                ch, on[0], on[1], off[0], off[1],
                obj.get("signal", {}).get(ch, 0.0), obj.get("noise", {}).get(ch, 0.0), UNITS[ch]))
        if obj.get("saturated"):
            body.append("      WARNING: clear channel saturated, lower the gain and repeat")
        self._write(stem, body, obj)
        if self.store and self.session_id:
            try:
                self.store.add_series(self.session_id, dict(obj, aperture=self.meta.get("aperture")), stem)
            except Exception as exc:
                print("[db] series not stored: %s" % exc, flush=True)
        return stem

    def report(self, obj):
        stem = "%s_report_%s_%s" % (
            datetime.now().strftime("%Y-%m-%d_%H%M"),
            self._slug(obj.get("light"), "light"),
            self._slug(self.meta.get("aperture"), "none"),
        )
        body = list(self._header(obj, "report"))
        body.append("")
        body.append("  ch     white     yellow   contrast    noise     SNR   verdict")
        for row in obj.get("channels", []):
            body.append("  %-5s %9.1f %9.1f %8.1f %%  %7.2f %7.1f   %s" % (
                row["ch"], row["white"], row["yellow"], row["contrast"] * 100.0,
                row["noise"], row["snr"], "GO" if row["go"] else "no"))
        body.append("")
        body.append("  best channel: %s  SNR=%.1f  ->  %s" % (
            obj.get("best", "none"), obj.get("best_snr", 0.0),
            "GO: optical readout is viable" if obj.get("go") else "NO-GO: contrast insufficient"))
        self._write(stem, body, obj)
        return stem
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

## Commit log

2026-09-12 feat: halo lab measurement software, firmware probe-0.5, test jig v6
    [gauge_jig_base.stl, jig_v5_pinhole_plates.stl, jig_v6_carrier.stl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]
2026-09-12 feat(labui): sqlite store, fix module import path
    [db.py, halo_lab.py]
2026-09-12 feat(labui): dark scrollbars, taller lists, export and point buttons
2026-09-12 feat(labui): logo seek animation, title glitch, clearer button states
2026-09-12 fix(labui): swing the logo sweep, working title glitch, cleaner buttons
2026-09-12 feat(labui): sequential footer ping, svg filter glitches, readable tabs
2026-09-12 fix(terminal): fast kiosk start, thin boot sweep, menu button in halo lab
2026-09-12 feat(cards): shift the dial so the fixed sensor sits on the measuring radius
2026-09-12 feat(labui): three stage measurement sequence, name with umlaut
2026-09-12 fix(labui): game buttons cannot confirm the dialog, sane ABXY mapping
2026-09-14 feat(labui): campaign unit, angle prompt, live curve
    [GK1_Mini_stand_v1.stl, halo_head_collar.stl, halo_head_lid.stl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]
2026-09-15 fix(labui): menu button back, menu off escape, guard the full screen key
2026-09-18 fix(labui): save buttons always reachable in the plan view

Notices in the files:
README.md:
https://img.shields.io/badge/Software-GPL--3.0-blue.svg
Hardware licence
